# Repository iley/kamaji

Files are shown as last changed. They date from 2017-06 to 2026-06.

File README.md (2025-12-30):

# Kamaji quiz game system

See [kamaji.cc](http://kamaji.cc) for assembly instructions and additional information.



Directories:

* `firmware`: main source code;
* `demo`: code samples;
* `3d`: [OpenSCAD](http://www.openscad.org/) models for the enclosure;
* `pcb`: schematic and printed circuit board layout in [KiCAD](http://kicad-pcb.org/) format;
* `misc`: the rest.

## SDK

We use [PlatformIO](http://platformio.org) with
[Arduino](http://platformio.org/frameworks/arduino) framework. It should also
be possible to compile the code with the official Arduino IDE.

## Compile and flash firmware

For v1 and v3 custom fuses must be programmed before first flashing.

```
pio run -e v1 -t fuses
```

Select the correct board version (v1, v2, v3) and flash it with:

```
pio run -e v1 -t upload
```

## Hardware

**The recommended version for new builds is "Classic V1".**

* V1 uses an ATmega328p running at 8MHz without an external oscillator. [USBasp](http://www.fischl.de/usbasp/) can be used for programming.
* V2 uses ATmega32u4 and a 128x64 graphics screen.
* V3 runs on ATmega328p with a 16MHz oscillator and and utilizes a PCF8574 I/O extender chip.
* "Classic V1" is an updated revision of V1. Fully compatible from software point of view.
* "Headless" is a USB MIDI device without a screen or buttons. Built around "Pro Micro" boards (ATMega32U4).

## Code style

Let's stick to [Google C++ Style Guide](https://google.github.io/styleguide/cppguide.html).

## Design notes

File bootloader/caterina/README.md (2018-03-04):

# ATMega32u4 bootloader

This is a slightly modified version of the [Sparkfan Arduino bootloader][sf].

Program with [USBasp][usbasp]:

    avrdude -p atmega32u4 -P usb -c usbasp \
        -U flash:w:Caterina.hex \
        -U efuse:w:0xcb:m -U hfuse:w:0xd8:m -U lfuse:w:0xff:m

Hot bo rebuild:

1. Install avr-gcc and avr-libc.
2. Download [LUFA][lufa] version 111009 into `LUFA` directory.
3. Run `make`.

[usbasp]: http://www.fischl.de/usbasp/
[sf]: https://github.com/sparkfun/SF32u4_boards/tree/master/sparkfun/avr/bootloaders/caterina
[lufa]: http://www.fourwalledcubicle.com/LUFA.php

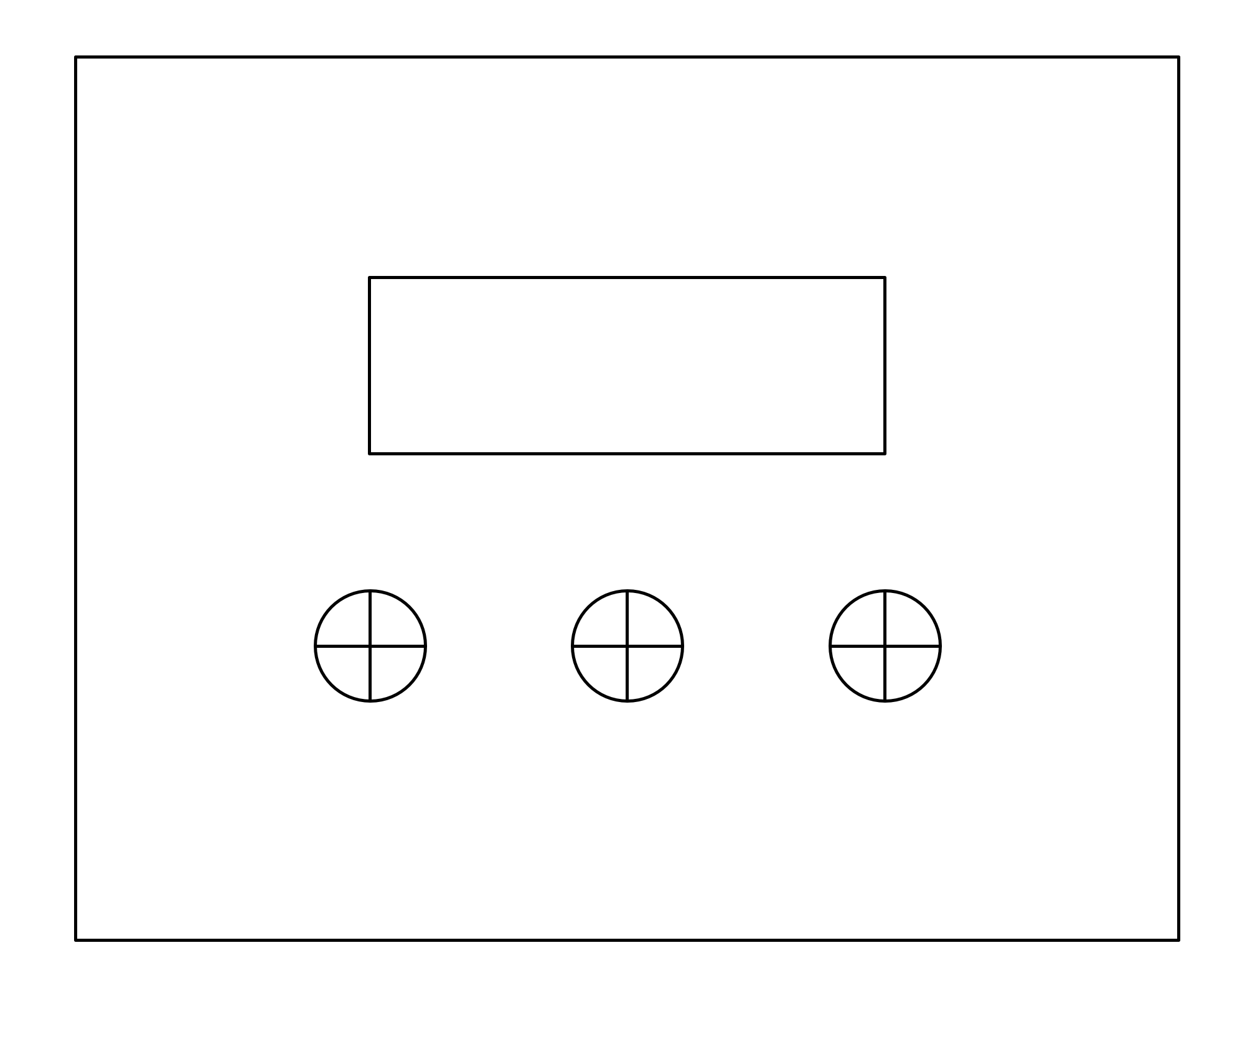
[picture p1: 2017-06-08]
misc/panel.png

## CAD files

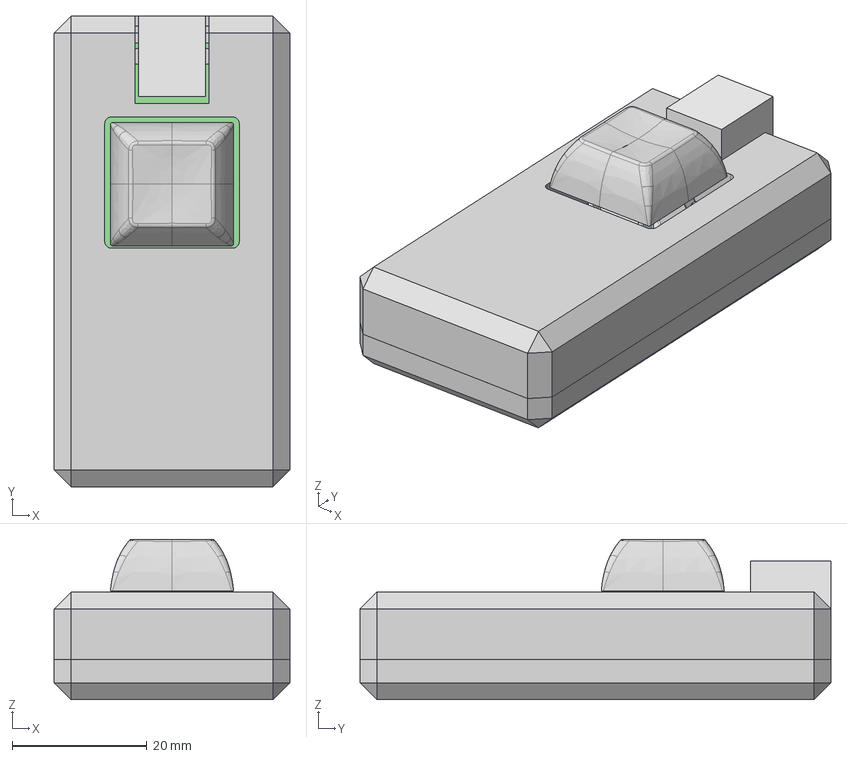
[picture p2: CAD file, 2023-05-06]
3d/button_v1/button_v1_shell.step
35.0 x 70.0 x 23.8 mm
kamaji_button_v1 PCB
SW_Cherry_MX_PCB v1
Keycap_adjusted v39 v1
case_top
case_bottom

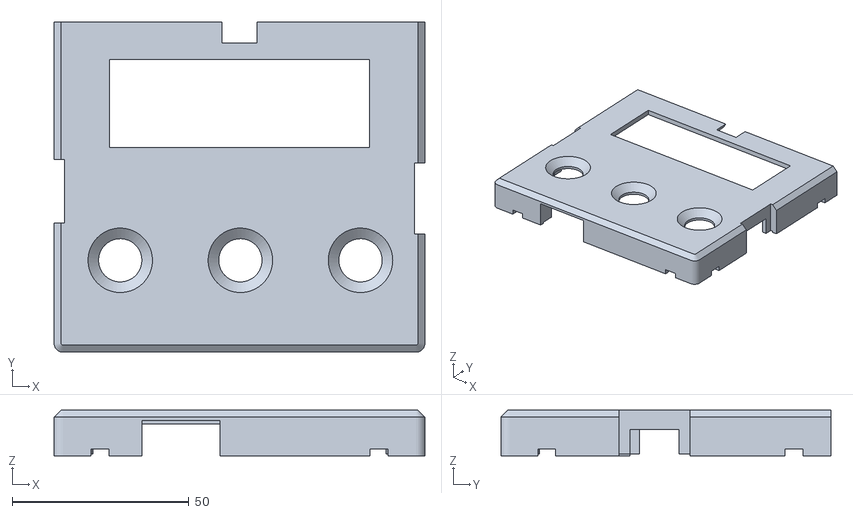
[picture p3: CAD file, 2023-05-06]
3d/classic_v1/kamaji_classic_v1_top.stl
105.0 x 93.5 x 13.0

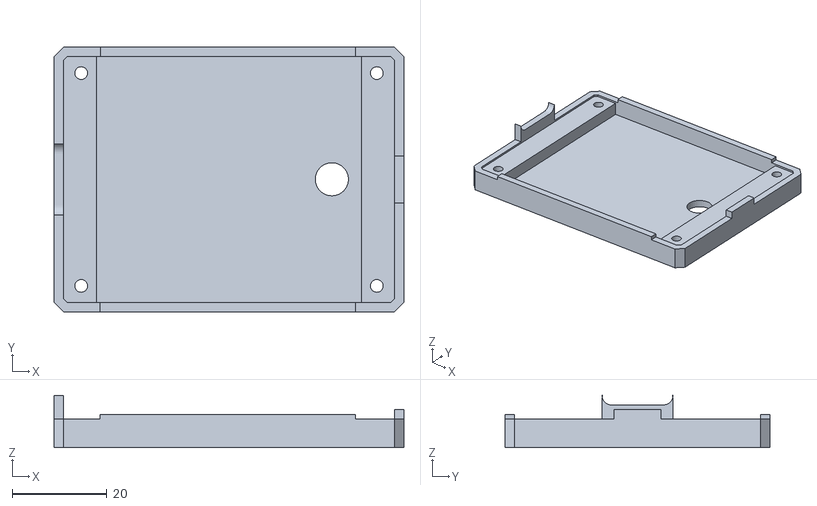
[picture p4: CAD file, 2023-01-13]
3d/headless_v1/bottom.stl
74.0 x 56.0 x 11.0

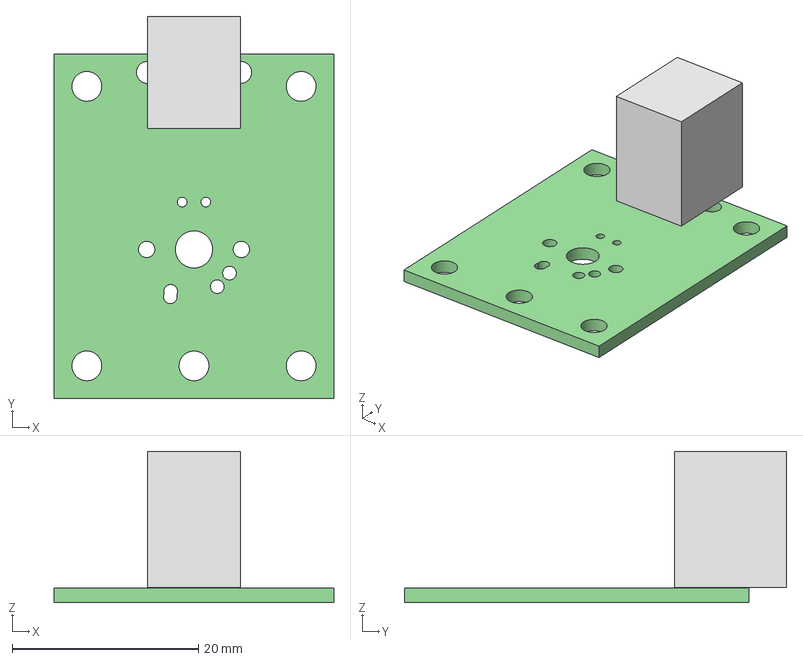
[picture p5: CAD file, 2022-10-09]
pcb/button_v1/kamaji_button_v1.STEP
30.0 x 41.0 x 16.2 mm
kamaji_button_v1 PCB

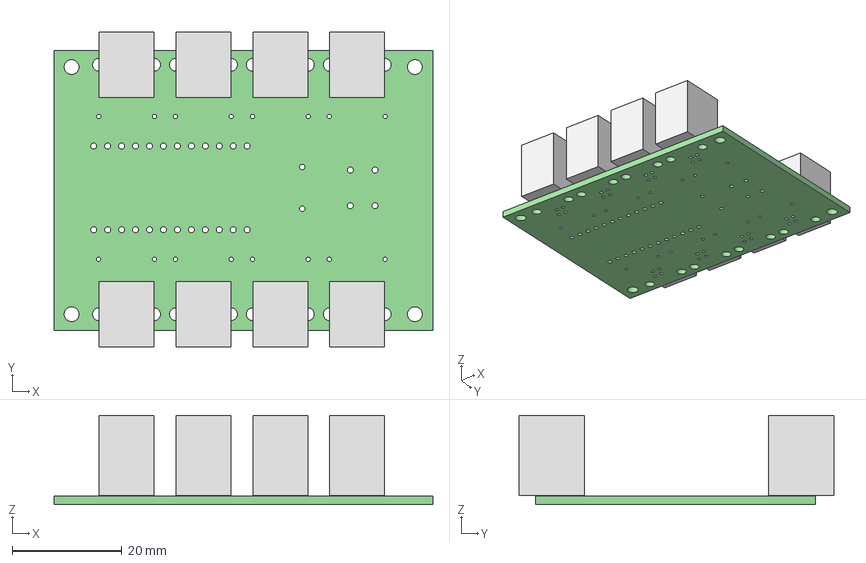
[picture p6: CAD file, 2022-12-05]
pcb/headless_v1/headless_v1.step
69.0 x 57.4 x 16.2 mm
headless_v1 PCB

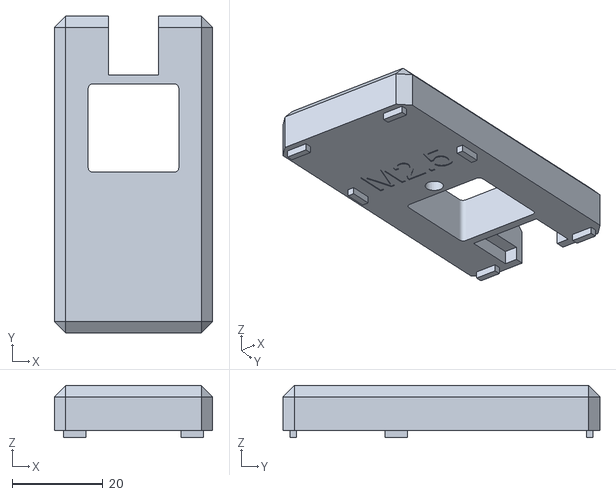
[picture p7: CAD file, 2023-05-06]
3d/button_v1/button_v1_top.stl
35.0 x 70.0 x 11.5

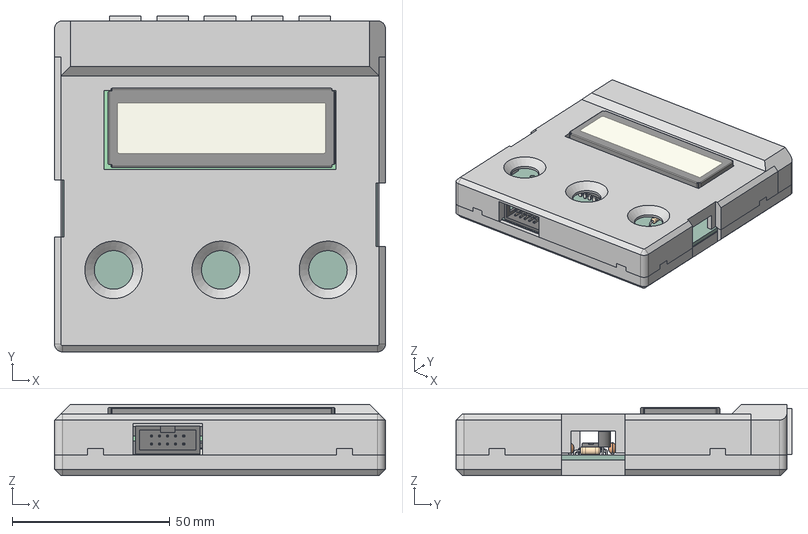
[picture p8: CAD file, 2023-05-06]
3d/classic_v1/kamaji_classic_v1_shell.step
105.0 x 106.5 x 22.6 mm
PCB
sockets_cover
top_shell
bottom_shell

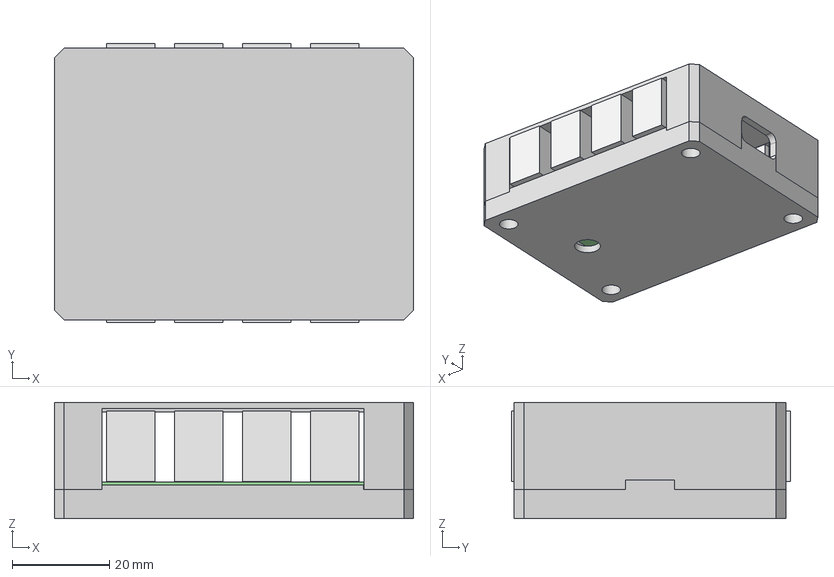
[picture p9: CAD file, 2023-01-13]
3d/headless_v1/kamaji_headless_v1.step
74.0 x 57.4 x 24.0 mm
headless_v1 PCB

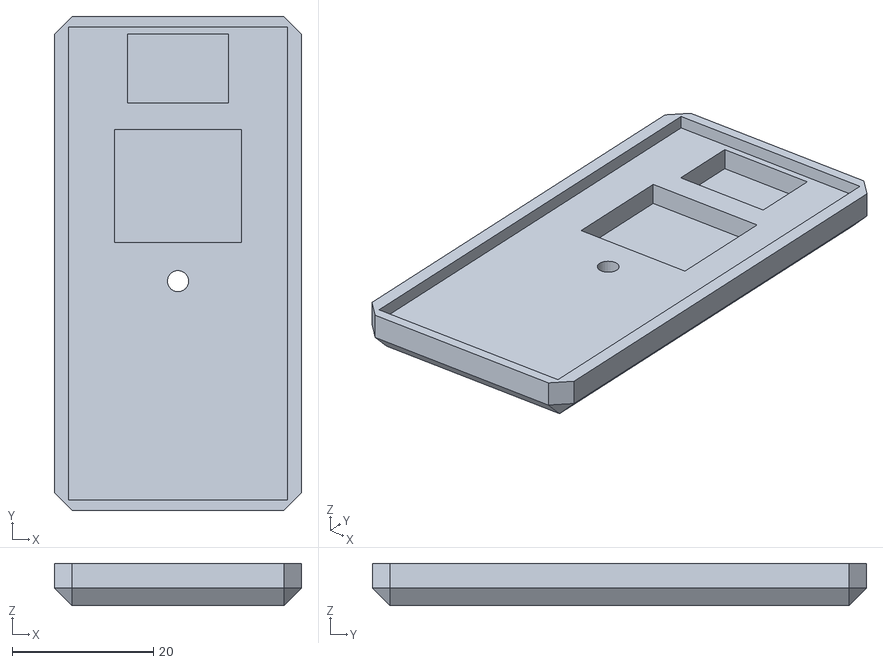
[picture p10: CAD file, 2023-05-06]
3d/button_v1/button_v1_bottom.stl
35.0 x 70.0 x 6.00

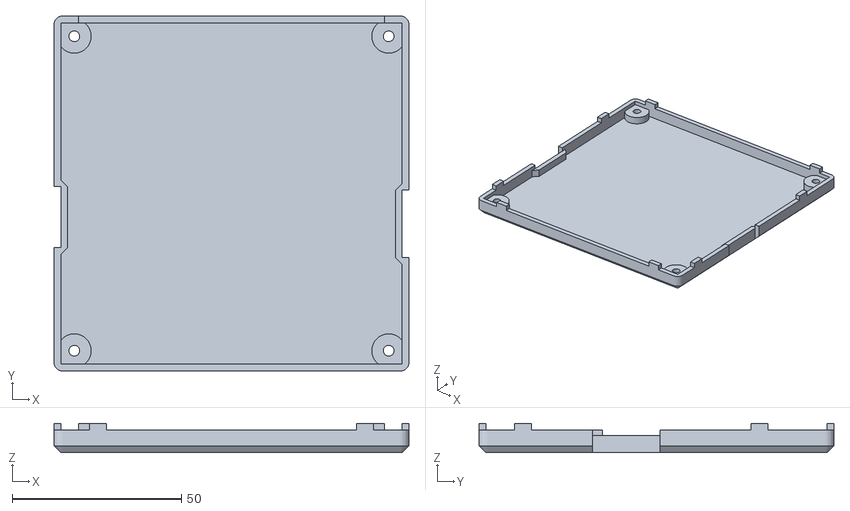
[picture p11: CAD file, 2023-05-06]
3d/classic_v1/kamaji_classic_v1_bottom.stl
105.0 x 105.0 x 8.60

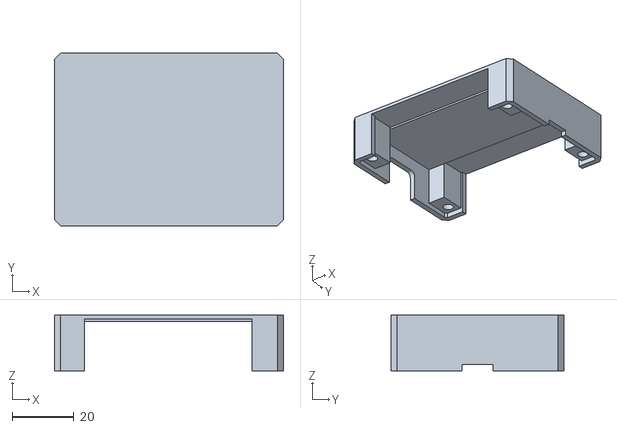
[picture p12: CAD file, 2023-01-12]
3d/headless_v1/top.stl
74.0 x 56.0 x 18.0

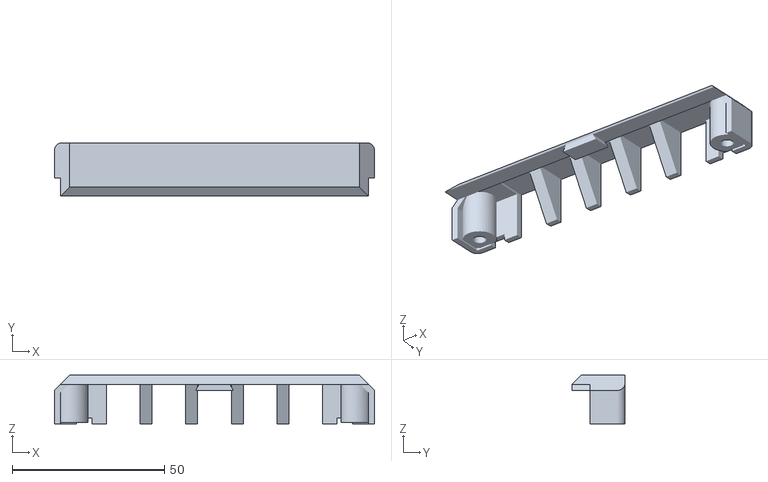
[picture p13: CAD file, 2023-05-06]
3d/classic_v1/kamaji_classic_v1_front_cover.stl
105.0 x 17.5 x 16.0

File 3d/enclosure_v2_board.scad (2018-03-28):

use <cubeX.scad>

tol = 0.25;
screen_tol = 0.8;
pcb_x = 100;
pcb_y = 100;
pcb_z = 4;
bolt_d = 3.6;
shift_bolt = 3;
shift_bolt_x = 4;
shift_bolt_y = 7;
board_w = 1;
board_h = 1;

m3_bolt_top_r = 2.9;
m3_bolt_top_h = 1.5;


// box thickness
th = 2;

// bolts
shift_x = th + 0.5;
shift_y = th + 0.5;

box_x = pcb_x + 2*th + 1;
box_y = pcb_y + 2*th + 1;

pcb_width = 1.8;

socket_h = 14.7;
socket_w = 10;
socket_n = 6;
socket_all_len = 85;
socket_int = socket_w + (socket_all_len - socket_n*socket_w)/(socket_n - 1);
start_socket_x = shift_x + (pcb_x - socket_all_len) / 2;
eps = 1e-1;

bottom_box_z = socket_h + th + pcb_width;

usb_type_b_w = 12;
usb_type_b_h = 11;
start_type_b_y = shift_y + pcb_y - 36.5;
start_type_b_z = bottom_box_z - pcb_width - usb_type_b_h - tol;

usb_type_a_w = 14.4;
usb_type_a_h = 6.3;
start_type_a_y = shift_y + 25;
start_type_a_z = bottom_box_z - pcb_width - usb_type_a_h - tol;

// programmator
micro_x = 10;
micro_y = 21.1;
micro_start_x = shift_x + 4.75;
micro_start_y = shift_y + pcb_y - 23.3 - micro_y;

contrast_start_x = shift_x + 38.4;
contrast_start_y = shift_y + 25.7;
//volume_start_x = shift_x + pcb_x - 39.2;
//volume_start_y = contrast_start_y;
pot_d = 7;
under_pcb = 13;
fn = 10;
gaika_h = 4;
gaika_w = 5.5;
stoiki_r = 4;
stoiki_h = socket_h;
wide_stoiki_r = stoiki_r + 2;

dynamic_x = shift_x + 19;
dynamic_y = shift_y + 30;
dynamic_r = 16;

volume_center_y = shift_y + 50;
volume_w = 15;
volume_start_y = volume_center_y - volume_w/2;
volume_h = 4;
round_radius=2;

translate([0,0,-50]) {

// put exclamation mark here to render bottom
difference() {
  union() {
    difference() {
      union() {
        cubeBottomX([box_x, box_y, bottom_box_z-board_h], radius=round_radius);
        translate([th - board_w, th - board_w, 0]) {
          cubeBottomX([box_x - 2*(th - board_w), box_y - 2*(th - board_w), bottom_box_z], radius=round_radius);
        }
      }
      translate([th, th, th]) {
        cubeBottomX([box_x-2*th+eps, box_y-2*th+eps, bottom_box_z-th+eps], radius=round_radius);
      }
    }
    // under_pcb, stoiki
    for (dy = [shift_y+shift_bolt_y, shift_y+pcb_y-shift_bolt_y]) {
      for (dx = [shift_x+shift_bolt_x, shift_x+pcb_x-shift_bolt_x]) {
        translate([dx,dy,th-eps]) {
          cylinder($fn=6, r=stoiki_r, h=stoiki_h + eps);
          //cylinder($fn=6, r=wide_stoiki_r, h=gaika_h);
        }
      }
    }
   translate([start_socket_x, th - eps, th - eps]) {
     cube([socket_all_len, th/2 + eps, stoiki_h + eps]);
   }
    //translate([box_x/2, box_y/2, th-eps]) {
      //cylinder($fn=6, r=stoiki_r, h=pcb_up);
    //}
  }

  // dynamic
  translate([dynamic_x, dynamic_y, -eps]) {
      cylinder($fn=20, r=dynamic_r, h = th+2*eps);
  }

  // sockets
  for (i = [0:1:socket_n-1]) {
      translate([start_socket_x+i*socket_int - tol, -eps, bottom_box_z - socket_h - pcb_width]) {
        cube(size=[socket_w + 2*tol, socket_h, socket_h + socket_h]);
      }
  }
  // bolts
  for (dx = [shift_x+shift_bolt_x, shift_x+pcb_x-shift_bolt_x]) {
    for (dy = [shift_y+shift_bolt_y, shift_y+pcb_y-shift_bolt_y]) {
      translate([dx,dy,-eps]) {
        cylinder($fn=fn, r=bolt_d/2, h=th+stoiki_h+2*eps);
        // bolt
        cylinder($fn=12, r=m3_bolt_top_r + 0.05, h=m3_bolt_top_h);
      }
    }
  }

//    // usb_in1 type b
    translate([box_x-th-eps, start_type_b_y-tol, start_type_b_z]) {
        cube(size=[th+2*eps, usb_type_b_w + 2*tol, bottom_box_z]);
    }

    // usb_out1 type a
    translate([box_x - eps - th, start_type_a_y - tol, start_type_a_z]) {
        cube(size=[th+2*eps, usb_type_a_w + 2*tol, bottom_box_z]);
    }

    // volume
    translate([-eps, volume_start_y, bottom_box_z - pcb_width - volume_h]) {
        cube(size=[th+2*eps, volume_w, volume_h + pcb_width + eps]);
    }

}
}

top_box_z = 10;
//stoiki_h = top_box_z - th;
wide_stoiki_h = 5;
pcb_room = 1;
screen_start_x = shift_x + 11.5;
screen_start_y = shift_y + 25;
screen_length_x = 77;
screen_length_y = 50.5;
screen_hold_x = 40;
screen_hold_y = 4;
screen_hold_start_z = 12.5;
screen_hold_y_shift = 2;
screen_hold_up_x = 15;
screen_hold_up_x_shift = 5;

master_button_y = shift_y + pcb_y - 7.5;
master_button_x = shift_x + 19;
master_button_int = 31.5;
master_button_r = 6.5;
top_bolt_h = 1.5;
top_bolt_r = 3.5;

// put exclamation mark here to render top
!rotate(a=[180,0,0]) {
difference() {
  union() {
    // board
    translate([0, 0, -board_h]) {
        difference() {
            cubeSideX(size=[box_x, box_y, board_h + eps], radius=round_radius, center=false);
            translate([board_w, board_w, -eps]) {
                cubeSideX(size=[box_x - 2*board_w, box_y - 2*board_w, board_h + 3*eps], radius=round_radius, center=false);
            }
        }
    }
    difference() {
      cubeTopX(size=[box_x,box_y,top_box_z], radius=round_radius, center=false);
      translate([th, th, -eps]) {
        cubeTopX(size=[box_x-2*th+eps, box_y-2*th+eps, top_box_z-th+eps], radius=round_radius, center=false);
      }
    }
    // stoiki
    for (dx = [shift_x+shift_bolt_x, shift_x+pcb_x-shift_bolt_x]) {
      for (dy = [shift_y+shift_bolt_y, shift_y+pcb_y-shift_bolt_y]) {
        translate([dx,dy,-eps]) {
          cylinder($fn=6, r=stoiki_r-0.5, h=top_box_z-th+eps);
        }
        translate([dx,dy,top_box_z-th-wide_stoiki_h+eps]) {
          cylinder($fn=6, r=wide_stoiki_r, h=wide_stoiki_h-2*eps);
        }
      }
    }
  }
  // bolts
  for (dx = [shift_x+shift_bolt_x, shift_x+pcb_x-shift_bolt_x]) {
    for (dy = [shift_y+shift_bolt_y, shift_y+pcb_y-shift_bolt_y]) {
      translate([dx,dy,-2*eps]) {
        cylinder($fn=fn, r=bolt_d/2, h=top_box_z+2*eps);
      }
      translate([dx, dy, top_box_z - wide_stoiki_h]) {
        cylinder($fn=6, r=gaika_w / 2 / cos(30) + 0.05, h=wide_stoiki_h+eps);
        //cylinder($fn=6, r=top_bolt_r, h=top_bolt_h + eps);
      }
    }
  }

  // screen
  translate([screen_start_x - screen_tol, screen_start_y - screen_tol, top_box_z - th - eps]) {
      cube([screen_length_x + 2*screen_tol, screen_length_y + 2*screen_tol, th + 2*eps]);
  }
  // master buttons
  for (i = [0:1:2]) {
    translate([master_button_x + master_button_int*i, master_button_y, top_box_z - th - eps]) {
      cylinder($fn=20, r=master_button_r + tol, h=th+2*eps);
    }
  }
}
}


//// bolts
//for (dx = [shift_x+shift_bolt, shift_x+pcb_x-shift_bolt]) {
//  for (dy = [shift_y+shift_bolt, shift_y+pcb_y-shift_bolt]) {
//    difference() {
//      translate([dx,dy,pcb_up/2+th]) {
//        cube(size=[a,a,pcb_up], center=true);
//      }
//      translate([dx,dy,-eps]) {
//        cylinder($fn=20, r=bolt_d/2, h=th+pcb_up+2*eps);
//      }
//    }
//  }
//}


//leg_r = t;
//shift = t/2+leg_r;
//for (dx = [shift, a-shift])
//    for (dy = [shift, b-shift]) {
//        translate([dx, dy, 0]) {
//            cylinder(h=c, r=leg_r, $fn=40);
//        }
//    }

module roundedRect(size, radius)
{
    x = size[0];
    y = size[1];
    z = size[2];
    translate([x/2,y/2,0]) {
    linear_extrude(height=z)
        hull()
        {
            // place 4 circles in the corners, with the given radius
            translate([(-x/2)+(radius/2), (-y/2)+(radius/2), 0])
                circle(r=radius);

            translate([(x/2)-(radius/2), (-y/2)+(radius/2), 0])
                circle(r=radius);

            translate([(-x/2)+(radius/2), (y/2)-(radius/2), 0])
                circle(r=radius);

            translate([(x/2)-(radius/2), (y/2)-(radius/2), 0])
                circle(r=radius);
        }
    }
}

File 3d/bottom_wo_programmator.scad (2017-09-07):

tol = 0.5;
pcb_x = 130;
pcb_y = 110;
pcb_z = 4;
bolt_d = 3.6;
shift_bolt = 5;

// box thickness
th = 2;

shift_x = 4;
shift_y = th + 1;

box_x = pcb_x + shift_x + 4;
box_y = pcb_y + shift_y + th;

pcb_width = 2;
pcb_up = 2;

box_z = th + pcb_up + pcb_width - 1;

socket_h = 15;
socket_w = 10;
socket_n = 5;
socket_int = 20;
start_socket_x = 20 + shift_x;
start_socket_z = th + pcb_z + tol;
eps = 1e-1;

usb_type_b_w = 12;
usb_type_b_h = 11;
start_type_b_y = shift_y + 81.5;
//start_type_b_z = th + pcb_z + tol;

usb_type_a_w = 13.4;
usb_type_a_h = 7.3;
start_type_a_y = shift_y + 47;
//start_type_a_z = th + pcb_z + tol;

// programmator
micro_x = 10;
micro_y = 21.1;
micro_start_x = shift_x + 4.75;
micro_start_y = shift_y + pcb_y - 23.3 - micro_y;

contrast_start_x = shift_x + 38.4;
contrast_start_y = shift_y + 25.7;
volume_start_x = shift_x + pcb_x - 39.2;
volume_start_y = contrast_start_y;
pot_d = 7;
fn = 10;
gaika_h = 2;
gaika_w = 5.6;
stoiki_r = 4;
wide_stoiki_r = stoiki_r + 2;



translate([0,0,-50]) {

!difference() {
  union() {
    difference() {
      cube([box_x,box_y,box_z], false);
      translate([th, th, th]) {
        cube([box_x-2*th+eps, box_y-2*th+eps, box_z-th+eps], false);
      }
    }
    // stoiki
    for (dy = [shift_y+shift_bolt, shift_y+pcb_y-shift_bolt]) {
      for (dx = [shift_x+shift_bolt, shift_x+pcb_x-shift_bolt]) {
        translate([dx,dy,th-eps]) {
          cylinder($fn=6, r=stoiki_r, h=pcb_up);
          cylinder($fn=6, r=wide_stoiki_r, h=gaika_h);
        }
      }
    }
    translate([box_x/2, box_y/2, th-eps]) {
      cylinder($fn=6, r=stoiki_r, h=pcb_up);
    }
  }

  // bolts
  for (dx = [shift_x+shift_bolt, shift_x+pcb_x-shift_bolt]) {
    for (dy = [shift_y+shift_bolt, shift_y+pcb_y-shift_bolt]) {
      translate([dx,dy,-eps]) {
        cylinder($fn=fn, r=bolt_d/2, h=th+pcb_up+2*eps);
        // gaika
        cylinder($fn=6, r=gaika_w / 2 / cos(30) + 0.05, h=gaika_h);
      }
    }
  }

//    for (i = [0:1:socket_n-1]) {
//        translate([start_socket_x+i*socket_int-tol, box_y-th-eps, start_socket_z]) {
//            cube(size=[socket_w+2*tol, th+2*eps, box_z]);
//        }
//    }

//    // usb_in1 type b
//    translate([box_x-th-eps, start_type_b_y-tol, start_type_b_z]) {
//        cube(size=[th+2*eps, usb_type_b_w+2*tol, box_z]);
//    }

//    // usb_out1 type a
//    translate([-eps, start_type_a_y - tol, start_type_a_z]) {
//        cube(size=[th+2*eps, usb_type_a_w + 2*tol, box_z]);
//    }

    // programmator
    //translate([micro_start_x-tol,micro_start_y-tol, -eps]) {
      //cube(size=[micro_x+2*tol, micro_y+2*tol, th+2*eps]);
    //}

    // contrast
    //translate([contrast_start_x, contrast_start_y, -eps]) {
      //cylinder($fn=fn, r=pot_d/2, h=th+2*eps);
    //}

    // volume
//    translate([volume_start_x, volume_start_y, -eps]) {
//      cylinder($fn=20, r=pot_d/2, h=th+2*eps);
//    }
}
}

top_box_z = 15 + th;
stoiki_h = top_box_z - th;
wide_stoiki_h = 2;
pcb_room = 0.5;
screen_start_x = shift_x + 28;
screen_start_y = shift_y + 40;
screen_length_x = 72;
screen_length_y = 24;
screen_hold_x = 40;
screen_hold_y = 4;
screen_hold_start_z = 12;
screen_hold_y_shift = 2;
screen_hold_up_x = 25;
screen_hold_up_x_shift = 5;

master_button_y = shift_y + 10;
master_button_x = shift_x + 43;
master_button_int = 21.8;
master_button_r = 3;
top_bolt_h = 1.5;
top_bolt_r = 3.5;
speaker_shift = 18;
speaker_r = 15;
speaker_h = 15;
speaker_hole_d = 10;
speaker_hole_int = 3;
speaker_hole_w = 1.5;
speaker_shift = 18;

difference() {
  union() {
    difference() {
      cube([box_x,box_y,top_box_z], false);
      translate([th, th, -eps]) {
        cube([box_x-2*th+eps, box_y-2*th+eps, top_box_z-th+eps], false);
      }
    }
    // stoiki
    for (dx = [shift_x+shift_bolt, shift_x+pcb_x-shift_bolt]) {
      for (dy = [shift_y+shift_bolt, shift_y+pcb_y-shift_bolt]) {
        translate([dx,dy,pcb_room]) {
	  cylinder($fn=6, r=stoiki_r, h=top_box_z-th+eps);
        }
        translate([dx,dy,top_box_z-th-wide_stoiki_h+eps]) {
	  cylinder($fn=6, r=wide_stoiki_r, h=wide_stoiki_h+th-2*eps);
        }
      }
    }
    // screen_hold
    translate([screen_start_x + (screen_length_x - screen_hold_x)/2, screen_start_y - screen_hold_y_shift - screen_hold_y, screen_hold_start_z]) {
	cube([screen_hold_x, screen_hold_y, top_box_z - screen_hold_start_z - th + eps]);
    }
    translate([screen_start_x + screen_length_x - screen_hold_up_x - screen_hold_up_x_shift, screen_start_y + screen_length_y + screen_hold_y_shift, screen_hold_start_z]) {
	cube([screen_hold_up_x, screen_hold_y, top_box_z - screen_hold_start_z - th + eps]);
    }
  }
  // - speaker na stoikah
  translate([shift_x + pcb_x - 18, shift_y + 18, 0]) {
    cylinder(r=speaker_r, h = 15, $fn=20);
  }
  // speaker_hole
  for (dy = [shift_y + speaker_shift - speaker_hole_int - speaker_hole_w*3/2, 
             shift_y + speaker_shift - speaker_hole_w/2, 
             shift_y + speaker_shift + speaker_hole_int + speaker_hole_w/2]) { 
    translate([shift_x + pcb_x - speaker_shift - speaker_hole_d, dy, top_box_z-th-eps]) {
      cube(size=[speaker_hole_d, speaker_hole_w, th + 2*eps]);
    }
  }

  // bolts
  for (dx = [shift_x+shift_bolt, shift_x+pcb_x-shift_bolt]) {
    for (dy = [shift_y+shift_bolt, shift_y+pcb_y-shift_bolt]) {
      translate([dx,dy,-eps]) {
        cylinder($fn=fn, r=bolt_d/2, h=top_box_z+2*eps);
      }
      translate([dx, dy, top_box_z - top_bolt_h]) {
        cylinder($fn=6, r=top_bolt_r, h=top_bolt_h + eps);
      }
    }
  }

  // screen
  translate([screen_start_x, screen_start_y, top_box_z - th - eps]) {
      cube([screen_length_x, screen_length_y + tol, th + 2*eps]);
  }
  // sockets
  for (i = [0:1:socket_n-1]) {
      translate([start_socket_x+i*socket_int-tol, box_y-th-eps, -eps]) {
	  cube(size=[socket_w+2*tol, th+2*eps, socket_h]);
      }
  }
  // type_b
  translate([box_x - th - eps, start_type_b_y - tol, -tol]) {
      cube([th + 2*eps, usb_type_b_w + 2*tol, usb_type_b_h + 2*tol]);
  }
  // type_a
  translate([-eps, start_type_a_y, -eps]) {
      cube([th + 2*eps, usb_type_a_w+eps, usb_type_a_h+2*eps]);
  }
  // master buttons
  for (i = [0:1:2]) {
    translate([master_button_x + master_button_int*i, master_button_y, top_box_z - th - eps]) {
      cylinder($fn=fn, r=master_button_r+tol, h=th+2*eps);
    }
  }
}


//// bolts
//for (dx = [shift_x+shift_bolt, shift_x+pcb_x-shift_bolt]) {
//  for (dy = [shift_y+shift_bolt, shift_y+pcb_y-shift_bolt]) {
//    difference() {
//      translate([dx,dy,pcb_up/2+th]) {
//        cube(size=[a,a,pcb_up], center=true);
//      }
//      translate([dx,dy,-eps]) {
//        cylinder($fn=20, r=bolt_d/2, h=th+pcb_up+2*eps);
//      }
//    }
//  }
//}


//leg_r = t;
//shift = t/2+leg_r;
//for (dx = [shift, a-shift])
//    for (dy = [shift, b-shift]) {
//        translate([dx, dy, 0]) {
//            cylinder(h=c, r=leg_r, $fn=40);
//        }
//    }

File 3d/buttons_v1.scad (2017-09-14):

$fn = 50;
button_h = 13;
overlap = 5;
//total_height = 22;
total_height = 19;
th = 2; // enclosure thickness
eps = 1e-1;

cap_r = 10.2 / 2;
cap_h = total_height - button_h + overlap;
cap_r_bottom = 3;

border_offset = 4 + th;
border_h = 3;
border_r = cap_r + 2;

socket_r = 3.2 / 2;

difference() {
  union() {
    cylinder(r=cap_r_bottom, h=cap_h);
    translate([0, 0, cap_h - border_h - border_offset]) {
      cylinder(r=border_r, h=border_h);
      cylinder(r=cap_r, h=border_h + border_offset);
    }
  }
  translate([0, 0, -eps]) {
    cylinder(r=socket_r, h=overlap+eps);
  }
}

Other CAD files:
3d/cubeX.scad
3d/classic_v1/kamaji_classic_v1_shell.f3z
3d/enclosure_v1.scad
3d/enclosure_v1_board.scad
3d/headless_v1/kamaji_headless_v1.f3z
3d/lcd_support_v1.scad
3d/legacy/cubeX.scad
3d/legacy/enclosure_v1.scad
3d/legacy/enclosure_v1_board.scad
3d/legacy/lcd_support_v1.scad

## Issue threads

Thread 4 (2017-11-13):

Visual signal for Brain Ring

ramosian-glider, 2017-11-13:
Replace it with something more handy, e.g. build a LED into the hull.

iley, 2017-11-13:
We may keep USB too in addition to an LED.

iley, 2017-11-13:
Possible options:
1) keep USB
2) add an LED on the hull
3) use a dedicated player button
4) signal using LEDs on the player buttons
5) replace the LED on player buttons with an RGB one

Closed 2018-03-04.

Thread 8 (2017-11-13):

Protection against powerbank auto-shutdown

iley, 2017-11-13:

iley, 2017-11-22:
Turning on a 100mA dummy load for 1 second every 10 seconds seems to work for the powerbanks we tested.

Closed 2017-12-22.

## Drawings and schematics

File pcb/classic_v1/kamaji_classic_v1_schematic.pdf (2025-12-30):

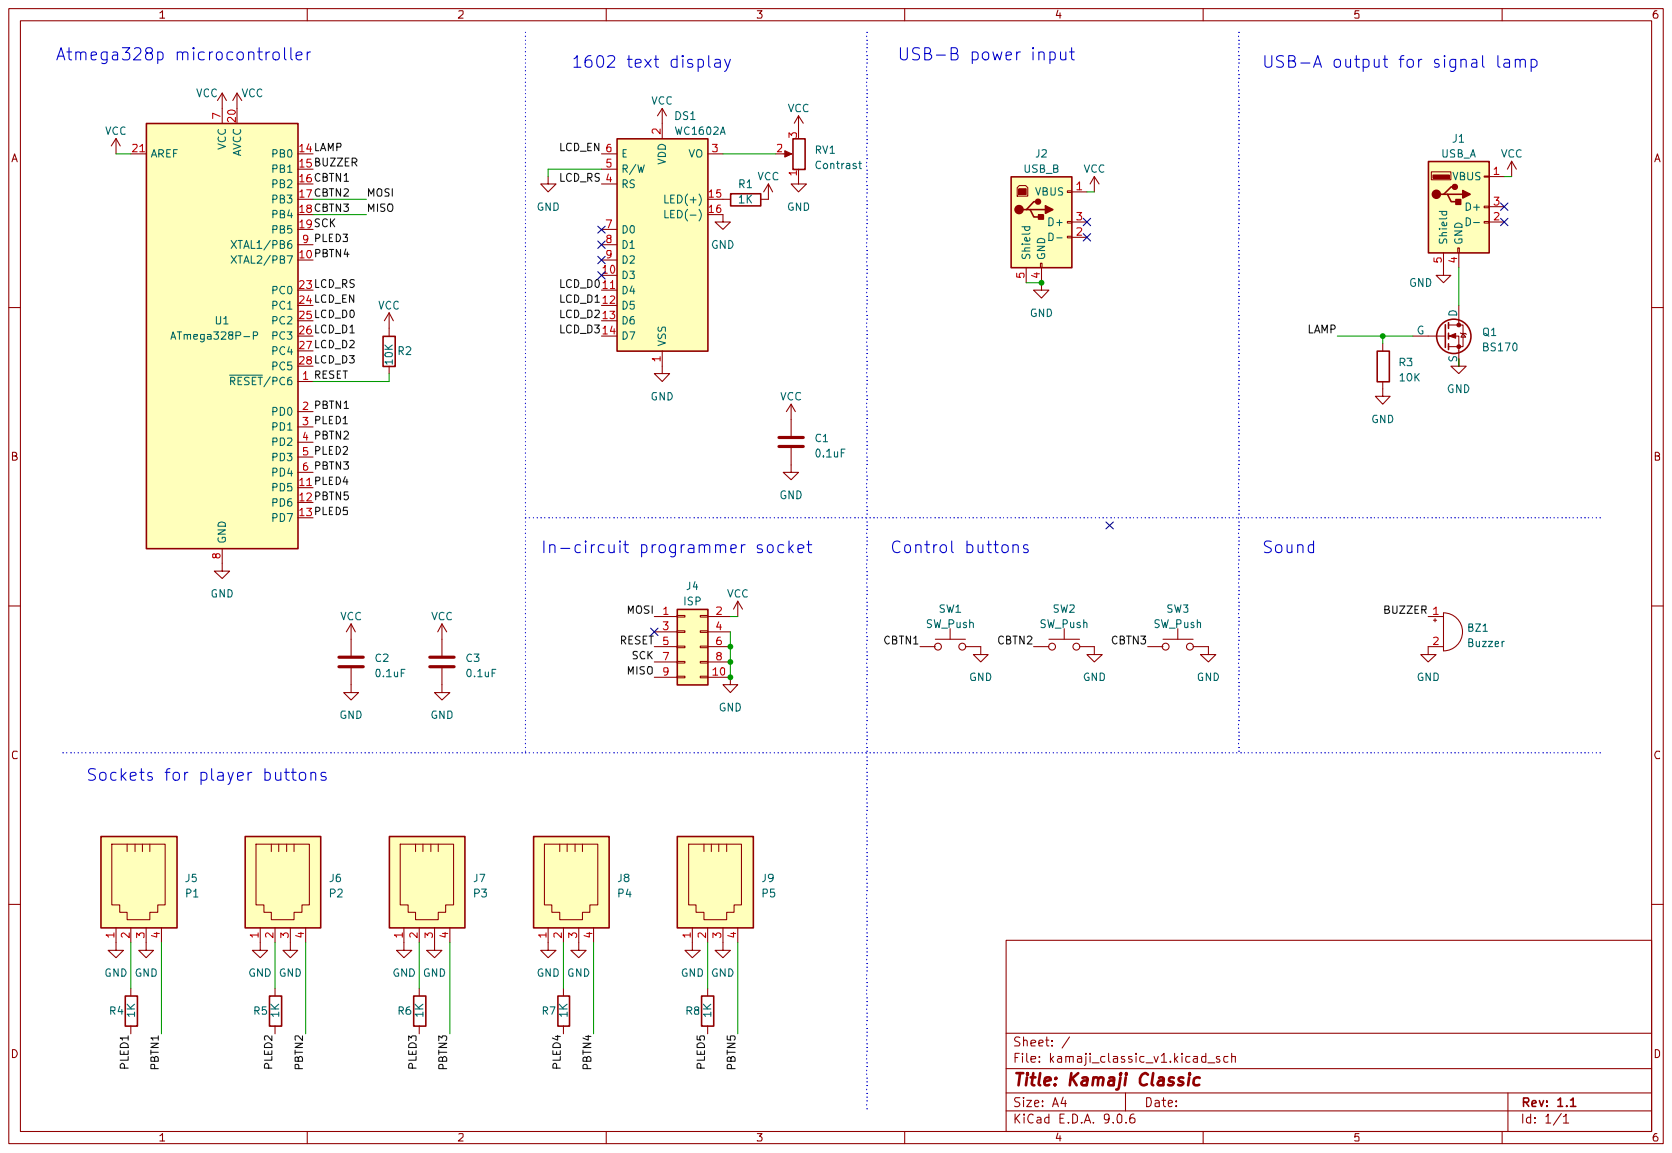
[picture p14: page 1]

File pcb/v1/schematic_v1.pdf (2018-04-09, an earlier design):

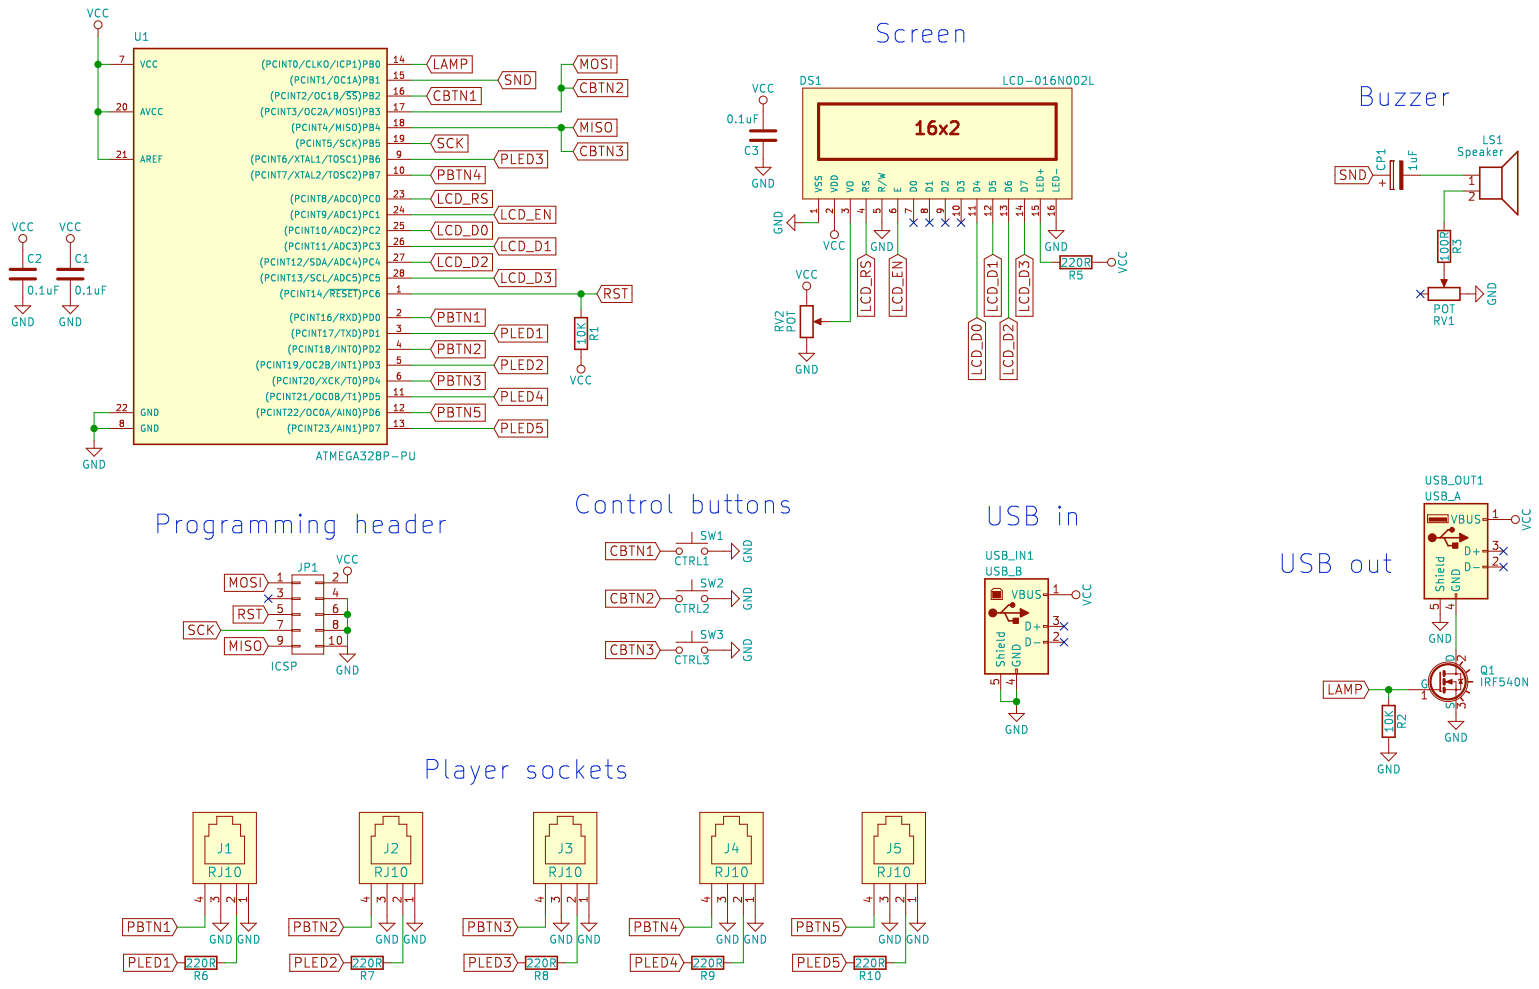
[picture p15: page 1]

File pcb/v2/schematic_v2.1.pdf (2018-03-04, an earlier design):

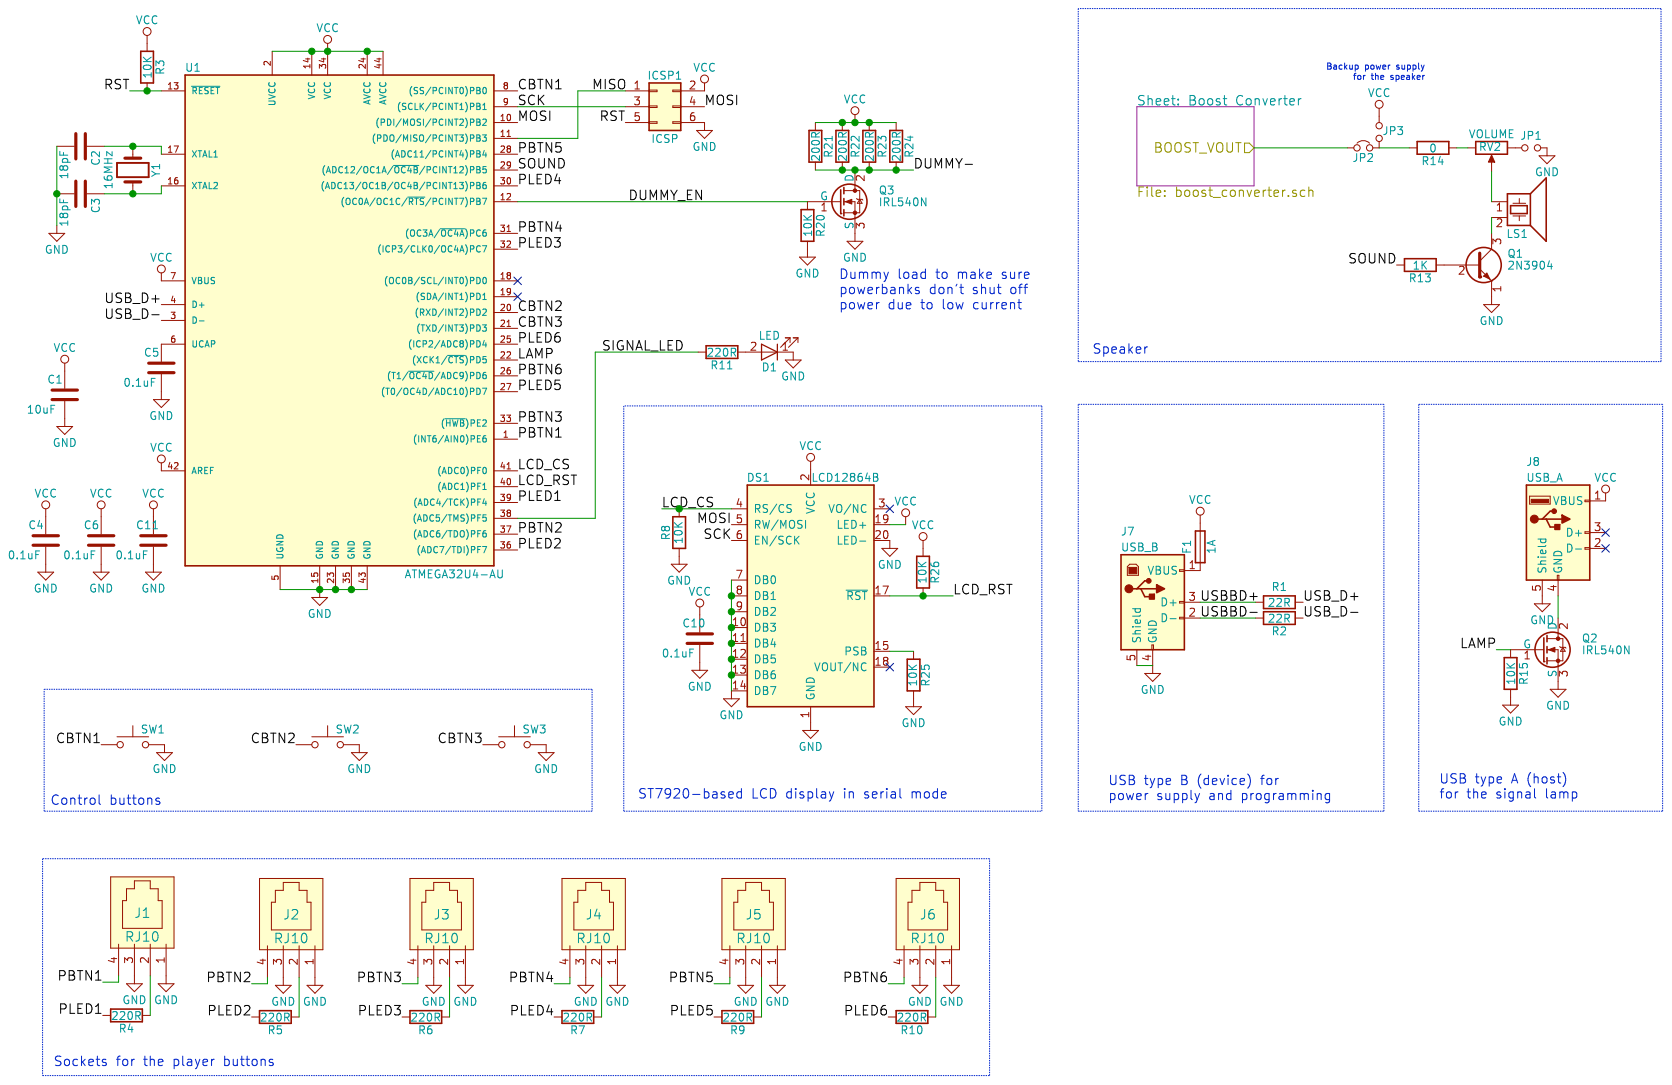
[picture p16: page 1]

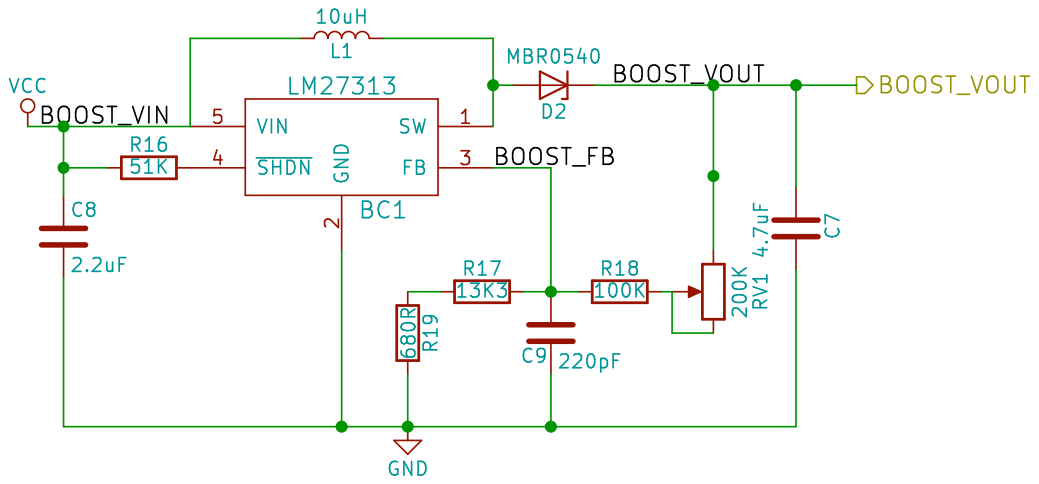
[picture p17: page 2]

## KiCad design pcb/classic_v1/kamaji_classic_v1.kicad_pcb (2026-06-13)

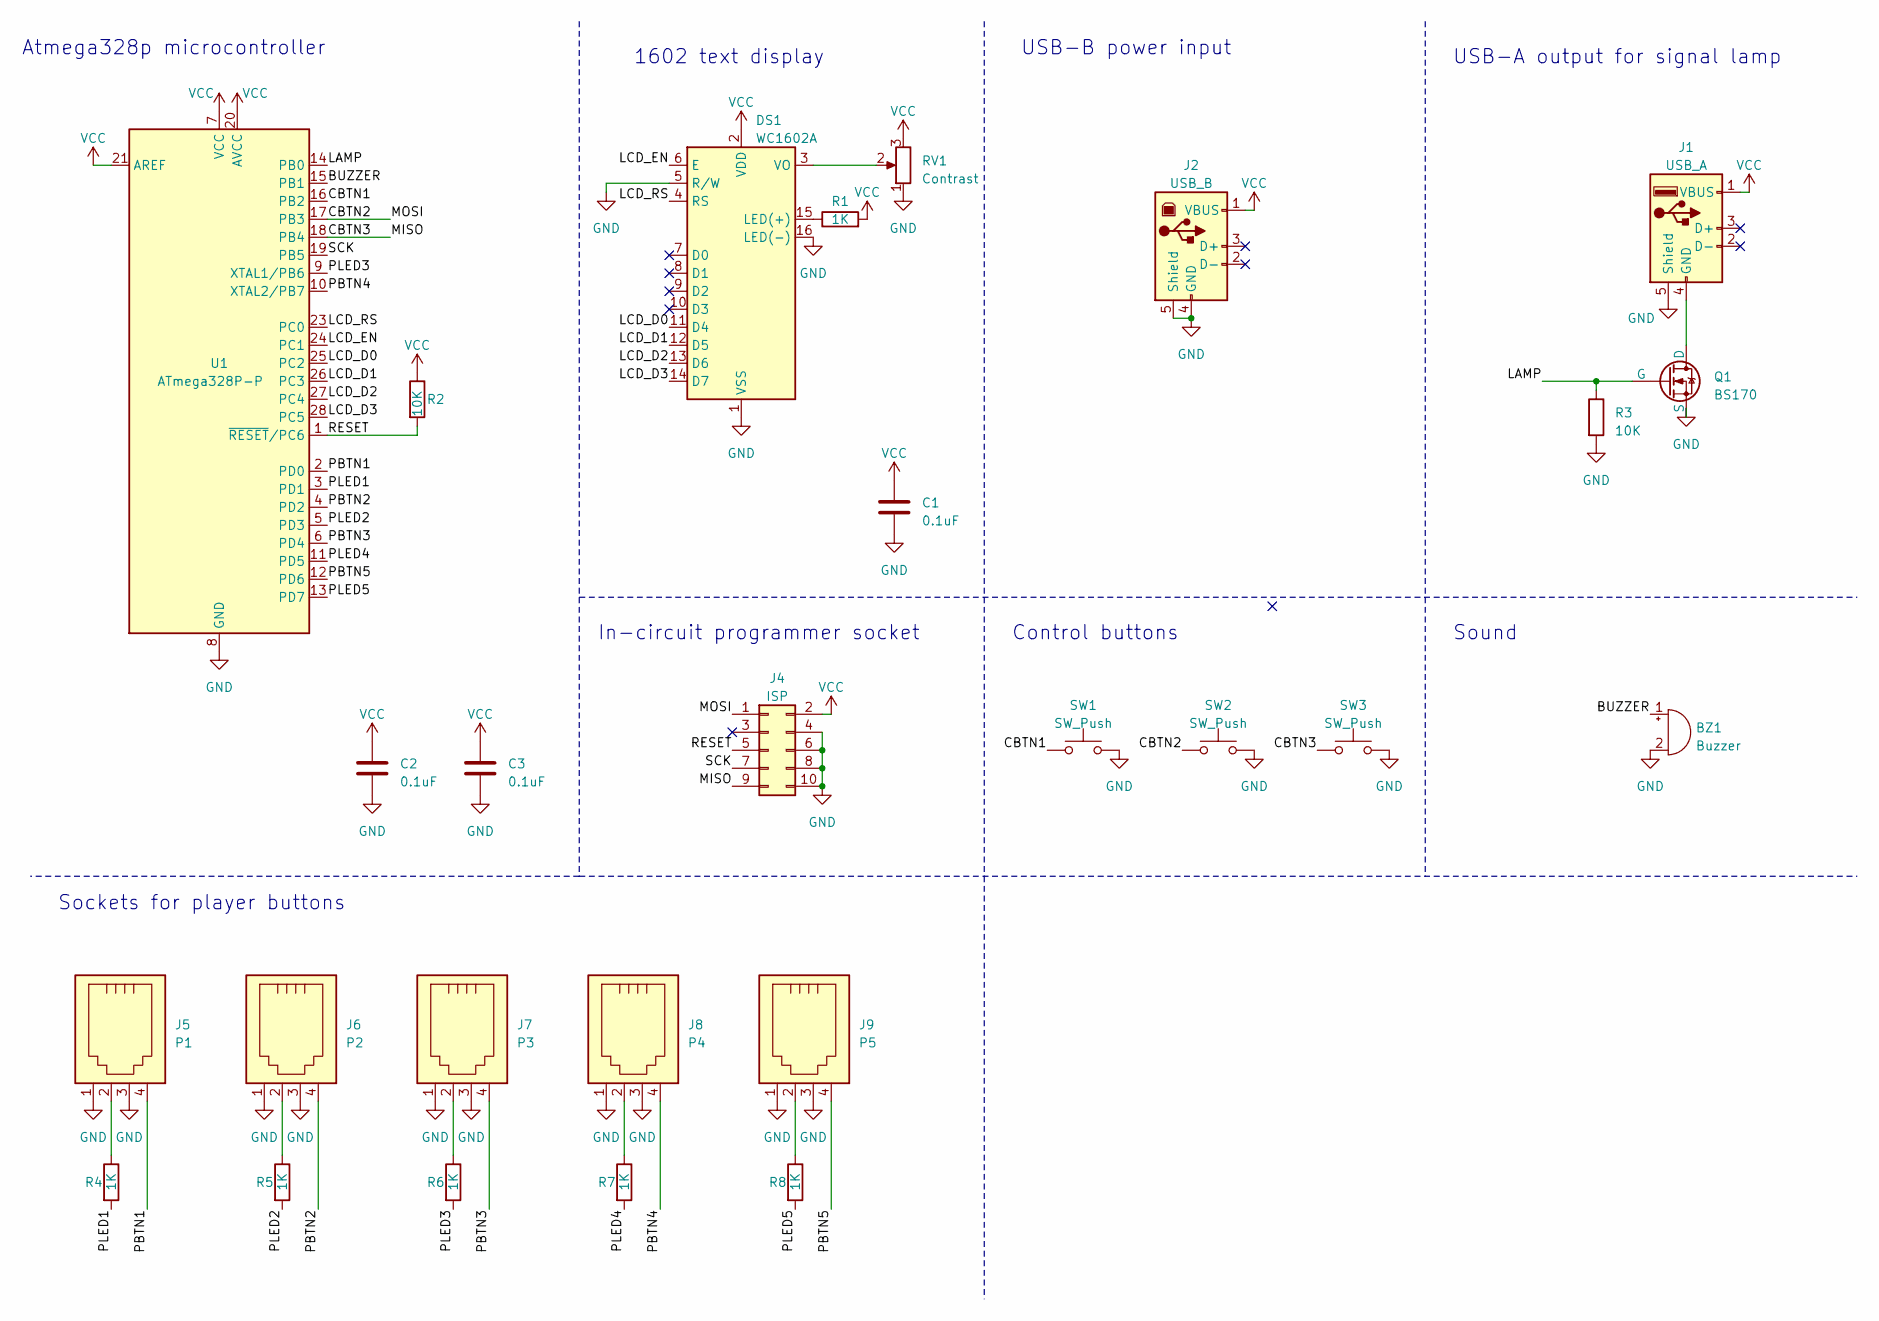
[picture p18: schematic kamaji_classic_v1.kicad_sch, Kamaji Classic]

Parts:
BZ1: Buzzer; Buzzer_12x9.5RM7.6
C1, C2, C3: 0.1uF; C_Disc_D3.8mm_W2.6mm_P2.50mm
DS1: WC1602A
J1: USB_A; USB_A_Connfly_DS1095
J2: USB_B; USB_B_Lumberg_2411_02_Horizontal
J4: ISP; IDC-Header_2x05_P2.54mm_Horizontal
J5: P1; RJ10
J6: P2; RJ10
J7: P3; RJ10
J8: P4; RJ10
J9: P5; RJ10
Q1: BS170; TO-92_HandSolder
R1, R4, R5, R6, R7, R8: 1K; R_Axial_DIN0207_L6.3mm_D2.5mm_P10.16mm_Horizontal
R2, R3: 10K; R_Axial_DIN0207_L6.3mm_D2.5mm_P10.16mm_Horizontal
RV1: Contrast; Potentiometer_Vishay_T73YP_Vertical
SW1, SW2, SW3: SW_Push; SW_PUSH-12mm
U1: ATmega328P-P; DIP-28_W7.62mm

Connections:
/BUZZER: BZ1.1 (-), U1.15 (PB1)
/CBTN1: SW1.1, U1.16 (PB2)
/CBTN2: J4.1, SW2.1, U1.17 (PB3)
/CBTN3: J4.9, SW3.1, U1.18 (PB4)
/LAMP: Q1.2 (G), R3.1, U1.14 (PB0)
/LCD_D0: DS1.11 (D4), U1.25 (PC2)
/LCD_D1: DS1.12 (D5), U1.26 (PC3)
/LCD_D2: DS1.13 (D6), U1.27 (PC4)
/LCD_D3: DS1.14 (D7), U1.28 (PC5)
/LCD_EN: DS1.6 (E), U1.24 (PC1)
/LCD_RS: DS1.4 (RS), U1.23 (PC0)
/PBTN1: J5.4, U1.2 (PD0)
/PBTN2: J6.4, U1.4 (PD2)
/PBTN3: J7.4, U1.6 (PD4)
/PBTN4: J8.4, U1.10 (XTAL2/PB7)
/PBTN5: J9.4, U1.12 (PD6)
/PLED1: R4.2, U1.3 (PD1)
/PLED2: R5.2, U1.5 (PD3)
/PLED3: R6.2, U1.9 (XTAL1/PB6)
/PLED4: R7.2, U1.11 (PD5)
/PLED5: R8.2, U1.13 (PD7)
/RESET: J4.5, R2.2, U1.1 (~RESET/PC6)
/SCK: J4.7, U1.19 (PB5)
GND: BZ1.2 (+), C1.2, C2.2, C3.2, DS1.1 (VSS), DS1.5 (R/W), DS1.16 (LED(-)), J1.5 (Shield), J2.4 (GND), J2.5 (Shield), J4.4, J4.6, J4.8, J4.10, J5.1, J5.3, J6.1, J6.3, J7.1, J7.3, J8.1, J8.3, J9.1, J9.3, Q1.3 (S), R3.2, RV1.1, SW1.2, SW2.2, SW3.2, U1.8 (GND), U1.22 (GND)
unnamed: DS1.15 (LED(+)), R1.1
unnamed: DS1.3 (VO), RV1.2
unnamed: J1.4 (GND), Q1.1 (D)
unnamed: J5.2, R4.1
unnamed: J6.2, R5.1
unnamed: J7.2, R6.1
unnamed: J8.2, R7.1
unnamed: J9.2, R8.1
VCC: C1.1, C2.1, C3.1, DS1.2 (VDD), J1.1 (VBUS), J2.1 (VBUS), J4.2, R1.2, R2.1, RV1.3, U1.7 (VCC), U1.20 (AVCC), U1.21 (AREF)

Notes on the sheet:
1602 text display
Atmega328p microcontroller
USB-B power input
Sockets for player buttons
Sound
Control buttons
USB-A output for signal lamp
In-circuit programmer socket

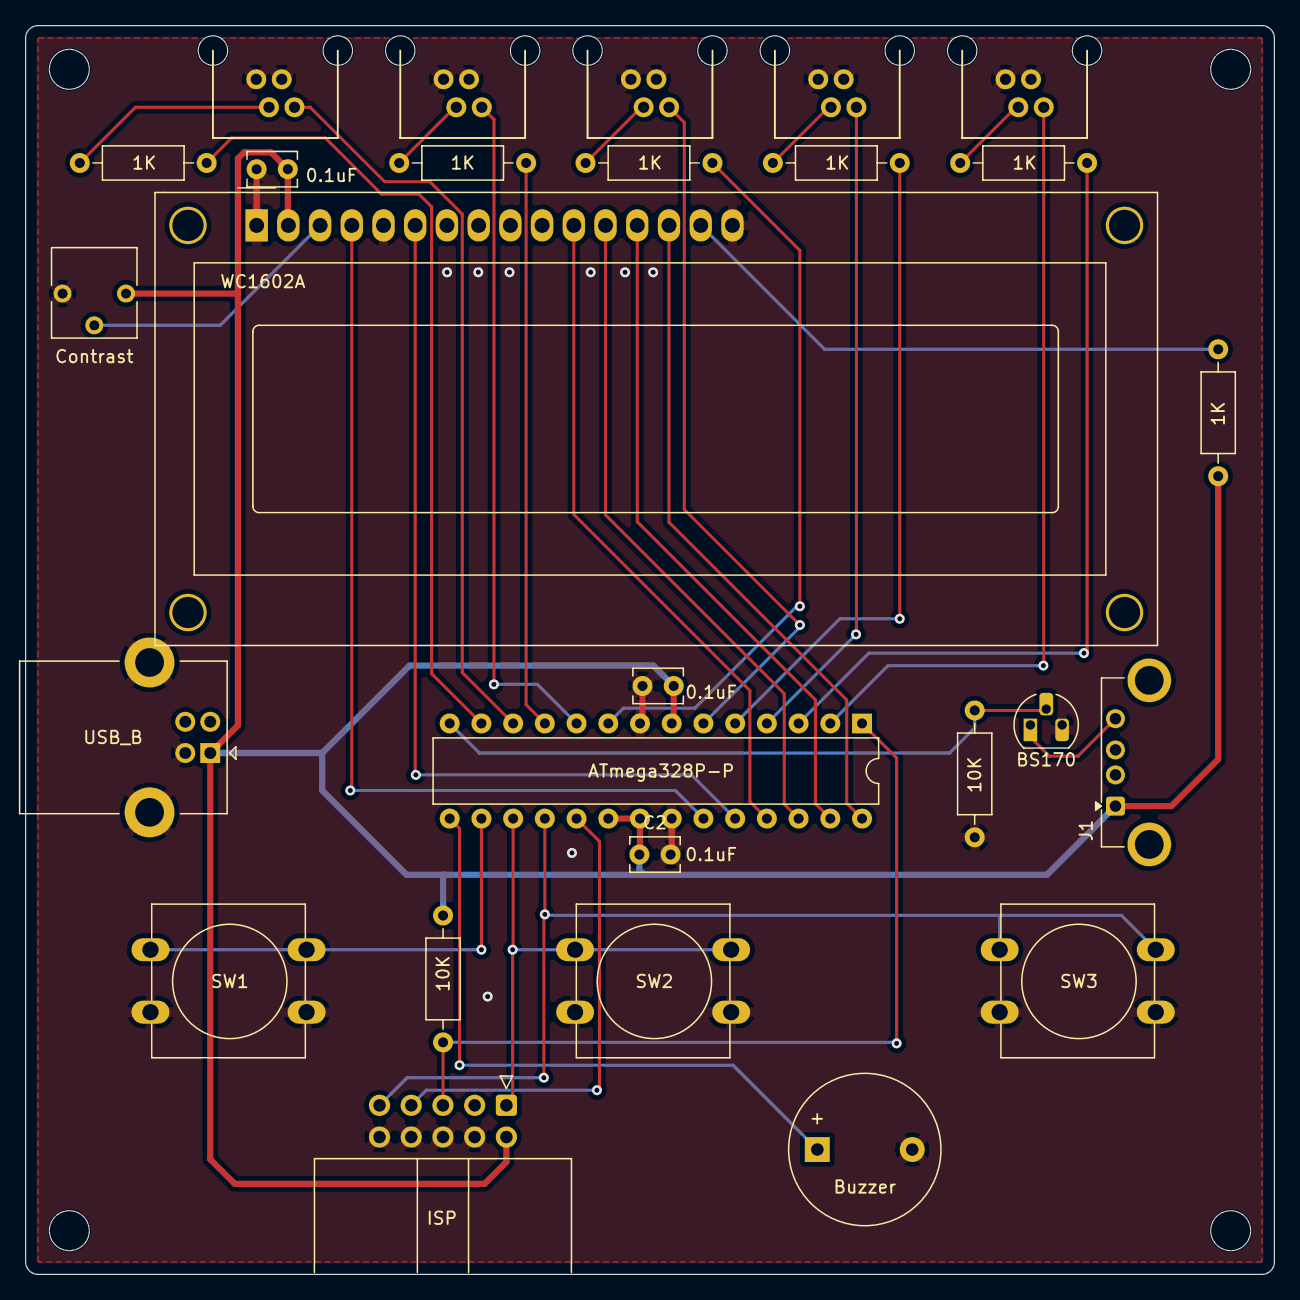
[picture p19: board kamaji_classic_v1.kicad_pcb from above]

Board: 2 copper layers, 100.0 x 100.0 mm, 27 parts (0 on the bottom side), 33 nets.

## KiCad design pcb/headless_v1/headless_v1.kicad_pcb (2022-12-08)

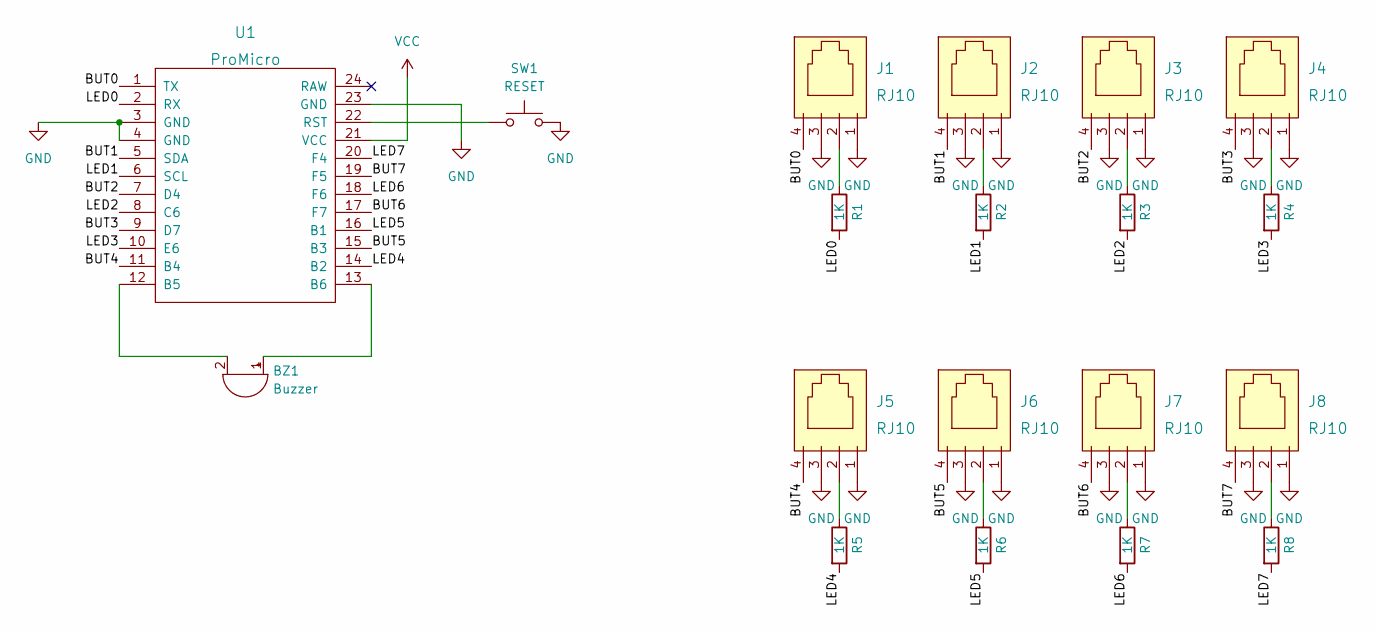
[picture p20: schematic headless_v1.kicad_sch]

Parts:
BZ1: Buzzer; Buzzer_12x9.5RM7.6
J1, J2, J3, J4, J5, J6, J7, J8: RJ10
R1, R2, R3, R4, R5, R6, R7, R8: 1K; R_Axial_DIN0207_L6.3mm_D2.5mm_P10.16mm_Horizontal
SW1: RESET; SW_PUSH_6mm
U1: ProMicro

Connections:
/BUT0: J1.4, U1.1 (TX)
/BUT1: J2.4, U1.5 (SDA)
/BUT2: J3.4, U1.7 (D4)
/BUT3: J4.4, U1.9 (D7)
/BUT4: J5.4, U1.11 (B4)
/BUT5: J6.4, U1.15 (B3)
/BUT6: J7.4, U1.17 (F7)
/BUT7: J8.4, U1.19 (F5)
/LED0: R1.2, U1.2 (RX)
/LED1: R2.2, U1.6 (SCL)
/LED2: R3.2, U1.8 (C6)
/LED3: R4.2, U1.10 (E6)
/LED4: R5.2, U1.14 (B2)
/LED5: R6.2, U1.16 (B1)
/LED6: R7.2, U1.18 (F6)
/LED7: R8.2, U1.20 (F4)
GND: J1.1, J1.3, J2.1, J2.3, J3.1, J3.3, J4.1, J4.3, J5.1, J5.3, J6.1, J6.3, J7.1, J7.3, J8.1, J8.3, SW1.2, U1.3 (GND), U1.4 (GND), U1.23 (GND)
unnamed: BZ1.1 (-), U1.13 (B6)
unnamed: BZ1.2 (+), U1.12 (B5)
unnamed: J1.2, R1.1
unnamed: J2.2, R2.1
unnamed: J3.2, R3.1
unnamed: J4.2, R4.1
unnamed: J5.2, R5.1
unnamed: J6.2, R6.1
unnamed: J7.2, R7.1
unnamed: J8.2, R8.1
unnamed: SW1.1, U1.22 (RST)
VCC: U1.21 (VCC)

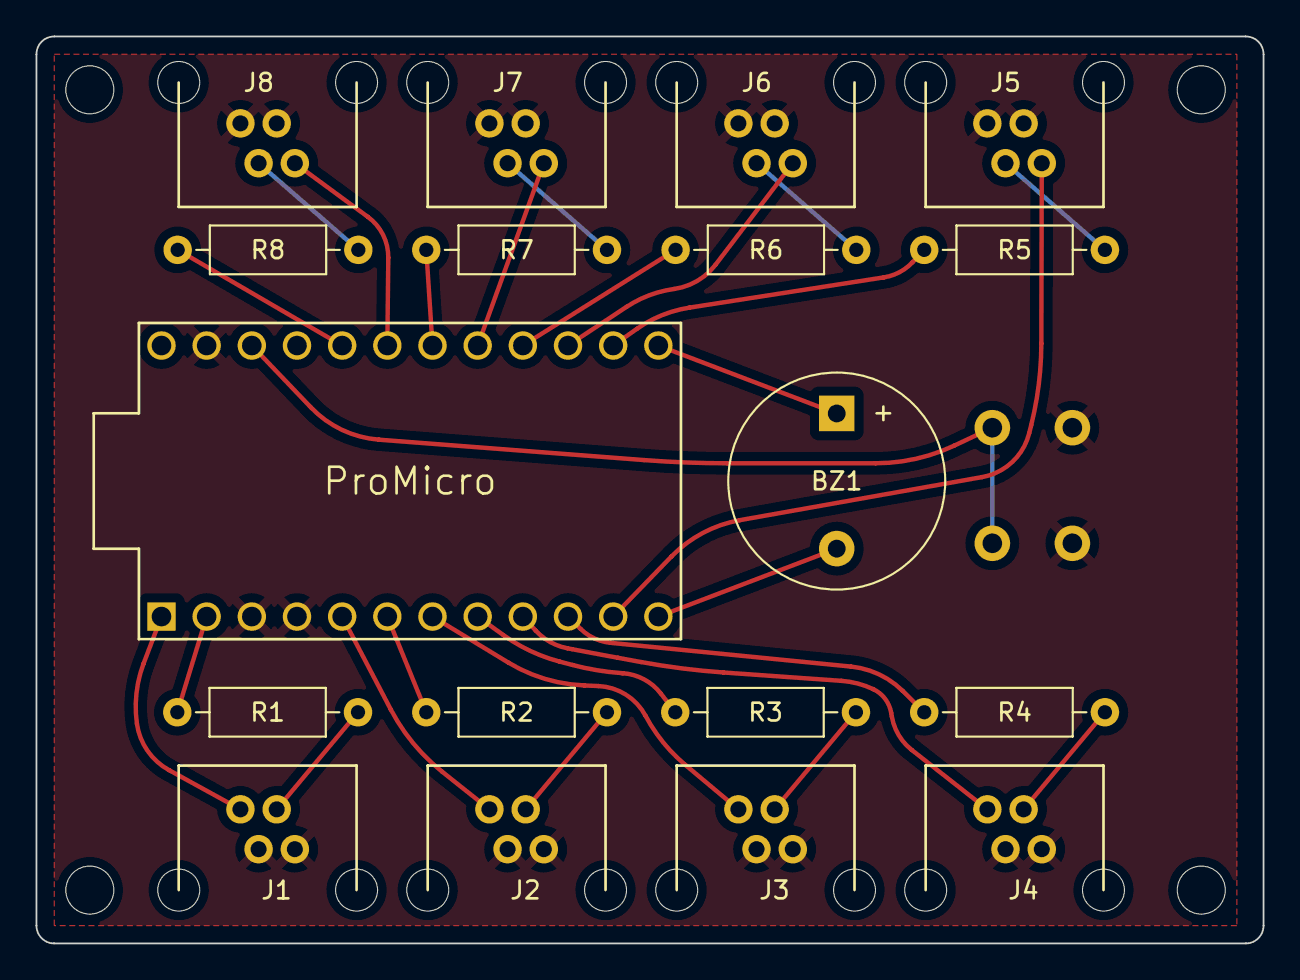
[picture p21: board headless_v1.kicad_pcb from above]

Board: 2 copper layers, 69.0 x 51.0 mm, 19 parts (1 on the bottom side), 28 nets.

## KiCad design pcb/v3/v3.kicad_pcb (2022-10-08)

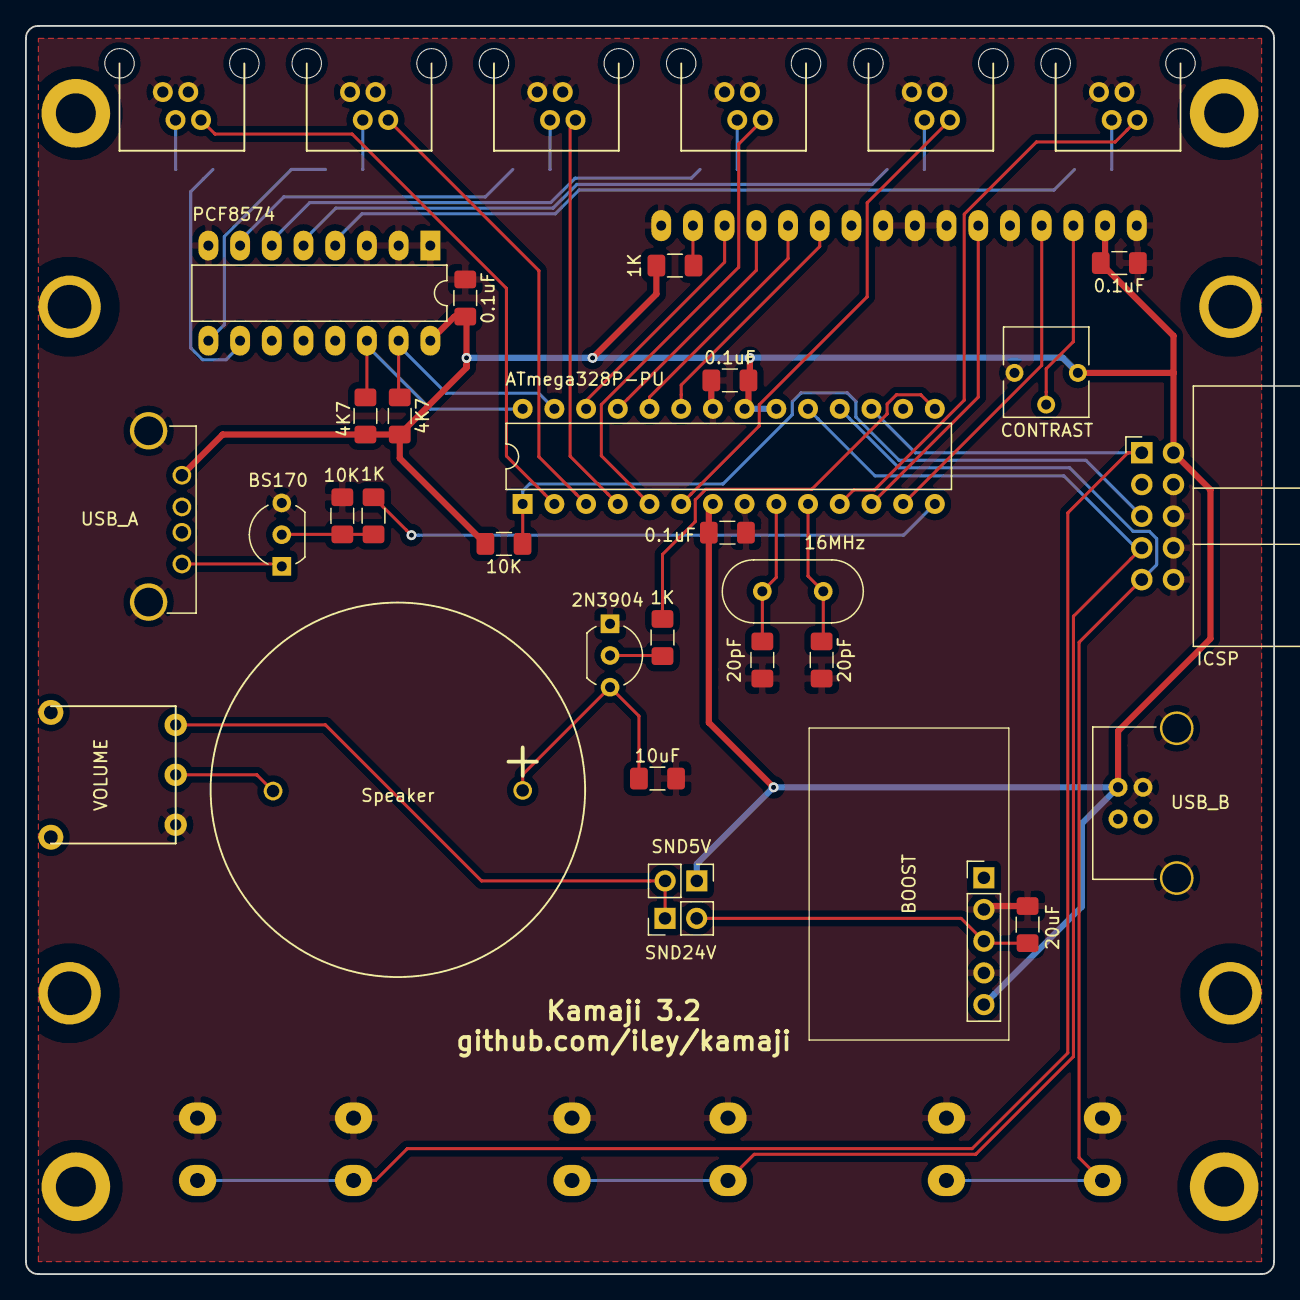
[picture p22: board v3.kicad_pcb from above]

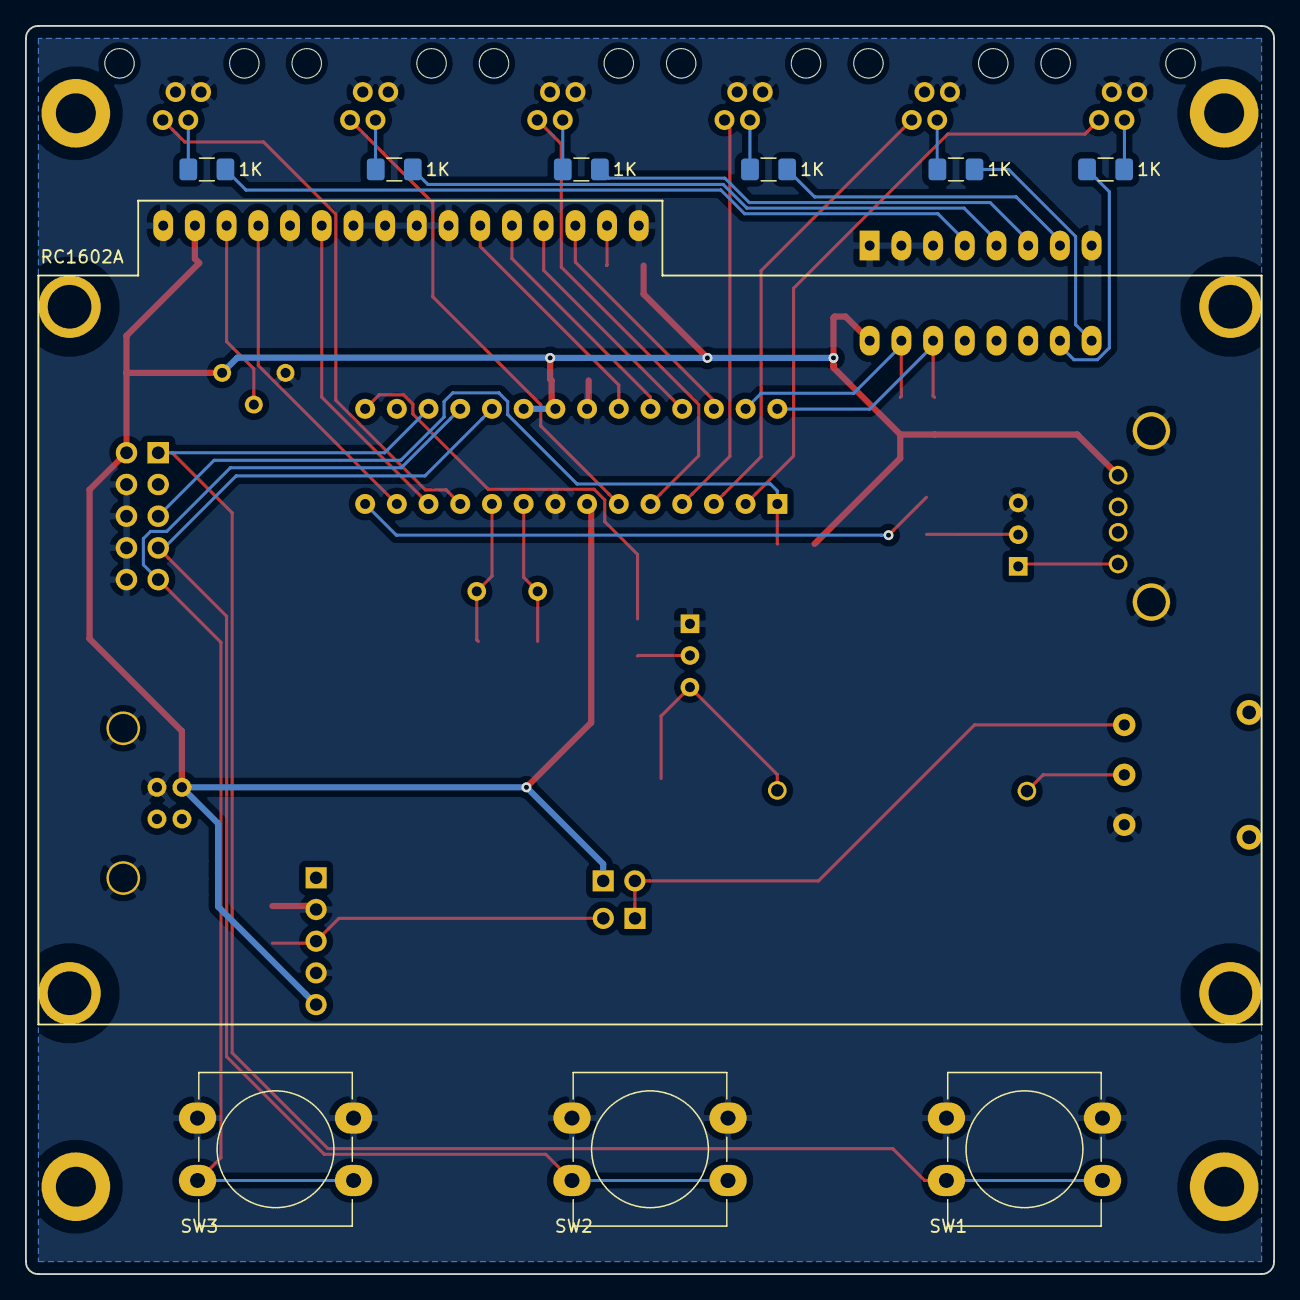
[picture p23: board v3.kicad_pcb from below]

Board: 2 copper layers, 100.0 x 100.0 mm, 45 parts (10 on the bottom side), 45 nets.

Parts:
C1, C4, C5, C7: 0.1uF; C_1206_3216Metric_Pad1.42x1.75mm_HandSolder
C2, C3: 20pF; C_1206_3216Metric_Pad1.42x1.75mm_HandSolder
C6: 20uF; C_1206_3216Metric_Pad1.42x1.75mm_HandSolder
C8: 10uF; C_1206_3216Metric_Pad1.42x1.75mm_HandSolder
J1, J3, J4, J5, J6, J7: RJ10
J2: ICSP; IDC-Header_2x05_P2.54mm_Horizontal
J8: BOOST; DD1718PA
J9: USB_B
J10: USB_A
JP1: SND24V; PinHeader_1x02_P2.54mm_Vertical
JP2: SND5V; PinHeader_1x02_P2.54mm_Vertical
LS1: Speaker; Buzzer_ARIO_98dB
Q2: 2N3904; TO-92_Inline_Wide
Q3: BS170; TO-92_Inline_Wide
R1, R2, R3, R5, R8, R9, R10, R12, R18: 1K; R_1206_3216Metric_Pad1.42x1.75mm_HandSolder
R4, R19: 10K; R_1206_3216Metric_Pad1.42x1.75mm_HandSolder
R6, R7: 4K7; R_1206_3216Metric_Pad1.42x1.75mm_HandSolder
RV1: CONTRAST; Potentiometer_Vishay_T73YP_Vertical
RV2: VOLUME; Potentiometer_Wheel_16mm
SW1: CTL1; Pushbutton_12mm
SW2: CTL2; Pushbutton_12mm
SW3: CTL3; Pushbutton_12mm
U1: ATmega328P-PU; DIP-28_W7.62mm
U2: PCF8574; DIP-16_W7.62mm_LongPads
U3: RC1602A; LCD2004
Y1: 16MHz; Crystal_HC49-U_Vertical

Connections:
+24V: C6.1, J8.3, JP1.2
/CBTN1: J2.1, SW1.1, U1.17
/CBTN2: J2.7, SW2.1, U1.19
/CBTN3: J2.9, SW3.1, U1.18
/LAMP: R18.2, U1.14
/LCD0: U1.23, U3.11
/LCD1: U1.24, U3.12
/LCD2: U1.25, U3.13
/LCD3: U1.26, U3.14
/LCDE: U1.12, U3.6
/LCDRS: U1.13, U3.4
/PBTN1: J1.4, U1.11
/PBTN2: J3.4, U1.6
/PBTN3: J4.4, U1.5
/PBTN4: J5.4, U1.4
/PBTN5: J6.4, U1.3
/PBTN6: J7.4, U1.2
/PLED1: R1.2, U2.4
/PLED2: R2.2, U2.5
/PLED3: R3.2, U2.6
/PLED4: R5.2, U2.7
/PLED5: R8.2, U2.9
/PLED6: R9.2, U2.10
/RST: J2.5, R4.2, U1.1
/SCL: R7.2, U1.28, U2.14
/SDA: R6.2, U1.27, U2.15
/SPK: R12.1, U1.15
/XTAL1: C2.2, U1.9, Y1.1
/XTAL2: C3.2, U1.10, Y1.2
GND: C1.2, C2.1, C3.1, C4.2, C5.2, C6.2, C7.2, C8.1, J1.1, J1.3, J2.4, J2.6, J2.8, J2.10, J3.1, J3.3, J4.1, J4.3, J5.1, J5.3, J6.1, J6.3, J7.1, J7.3, J8.2, J8.4, J9.4, J9.5, J10.5, Q2.1, Q3.3, R19.2, RV1.1, RV2.1, SW1.2, SW2.2, SW3.2, U1.8, U1.22, U2.1, U2.2, U2.3, U2.8, U3.1, U3.5, U3.7, U3.8, U3.9, U3.10, U3.16
unnamed: C8.2, LS1.1, Q2.3
unnamed: J1.2, R1.1
unnamed: J3.2, R2.1
unnamed: J4.2, R3.1
unnamed: J5.2, R5.1
unnamed: J6.2, R8.1
unnamed: J7.2, R9.1
unnamed: J10.4, Q3.1
unnamed: JP1.1, JP2.2, RV2.3
unnamed: LS1.2, RV2.2
unnamed: Q2.2, R12.2
unnamed: Q3.2, R18.1, R19.1
unnamed: R10.1, U3.15
unnamed: RV1.2, U3.3
VCC: C1.1, C4.1, C5.1, C7.1, J2.2, J8.5, J9.1, J10.1, JP2.1, R4.1, R6.1, R7.1, R10.2, RV1.3, U1.7, U1.20, U1.21, U2.16, U3.2

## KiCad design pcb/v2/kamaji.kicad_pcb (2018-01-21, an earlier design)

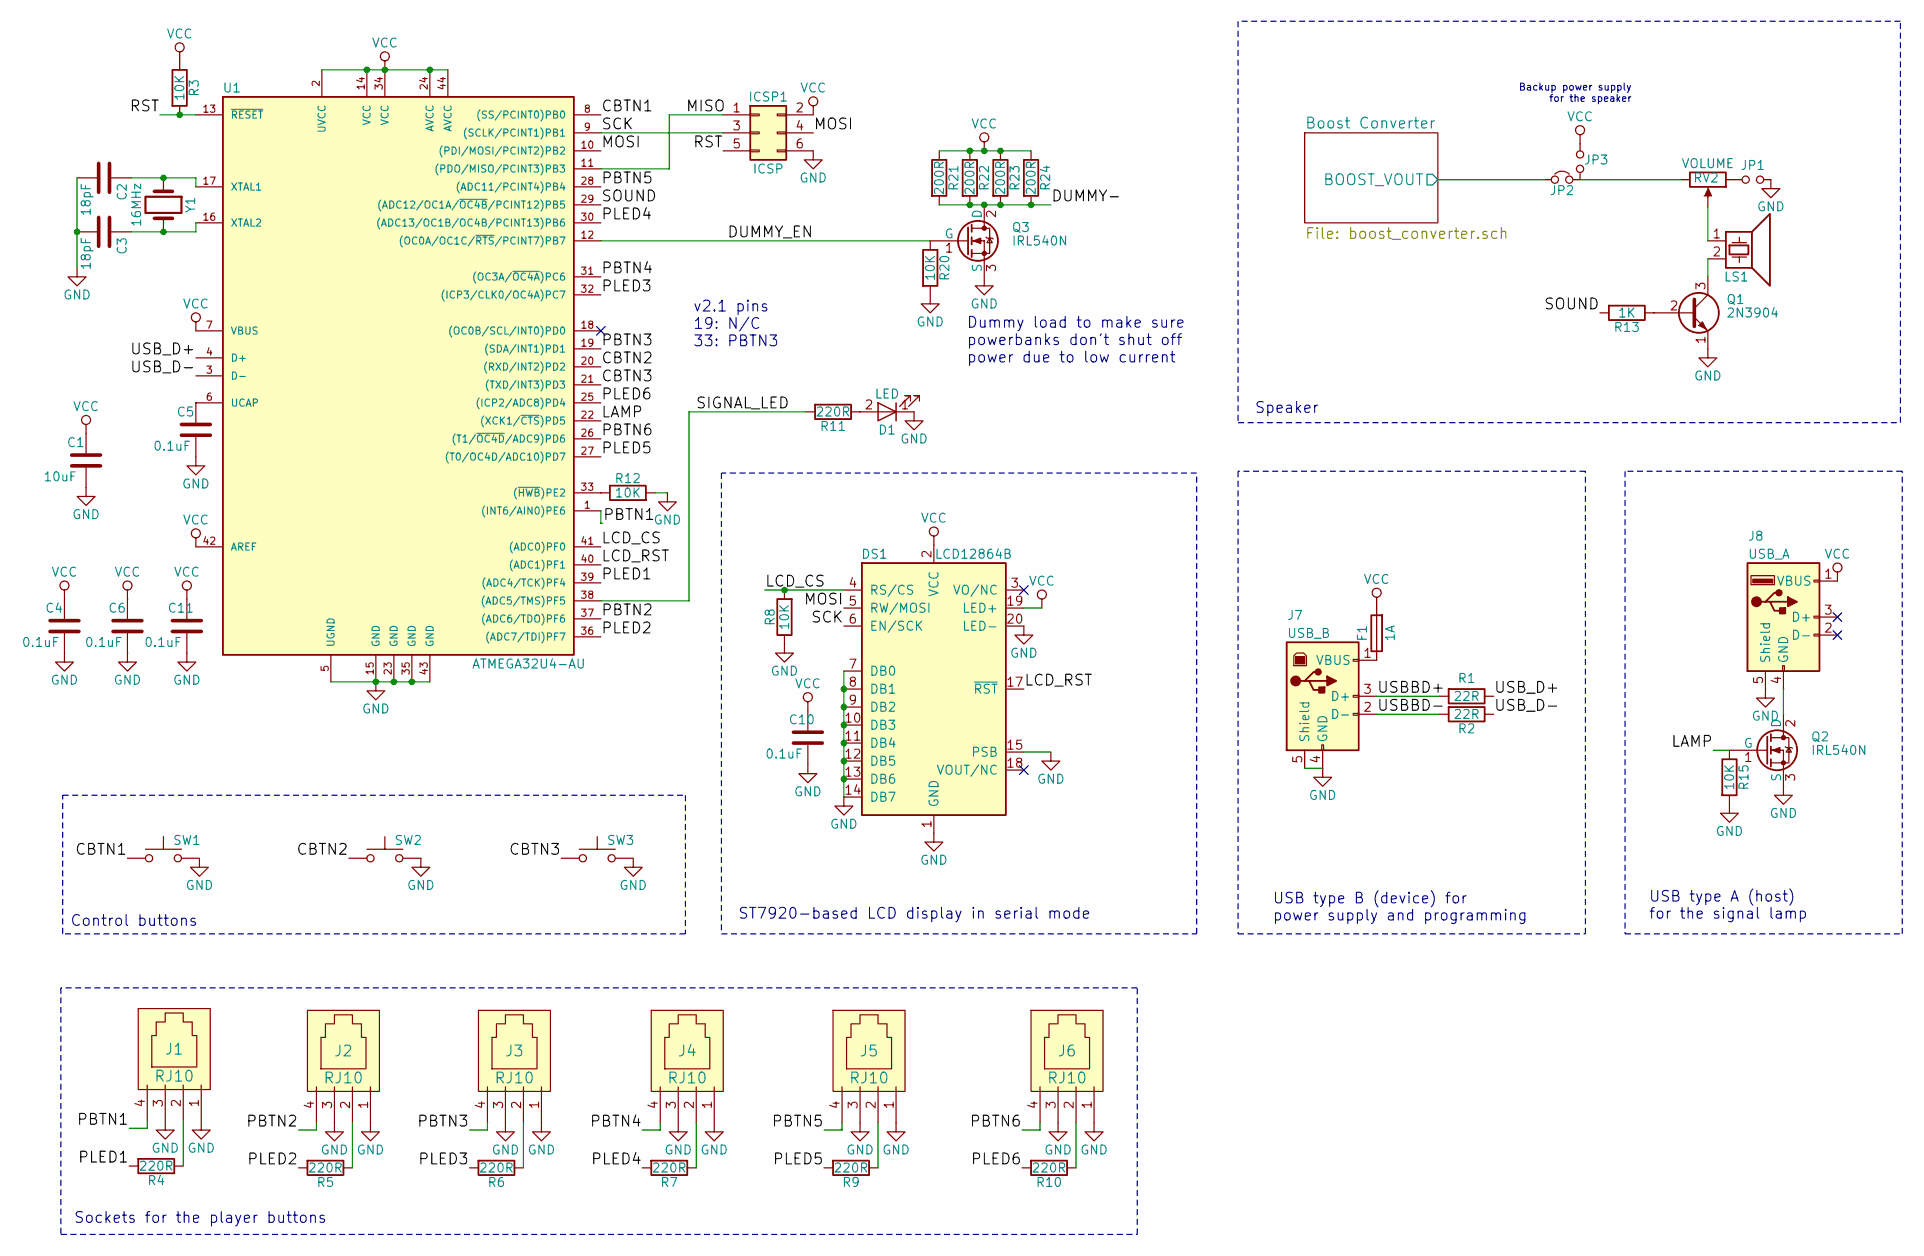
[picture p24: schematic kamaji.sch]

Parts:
C1: 10uF; C_1206_HandSoldering
C2, C3: 18pF; C_1206_HandSoldering
C4, C5, C6, C10, C11: 0.1uF; C_1206_HandSoldering
D1: LED; LED_D5.0mm
DS1: LCD12864B; LCD12864
F1: 1A; R_1812_HandSoldering
ICSP1: ICSP; ATmega_ISP_6pin
J1, J2, J3, J4, J5, J6: RJ10
J7: USB_B
J8: USB_A
JP1: Jumper_NO_Small; Pin_Header_Straight_1x02_Pitch2.54mm
JP2: Jumper_NC_Small; Pin_Header_Straight_1x02_Pitch2.54mm
JP3: SoundVcc2; Pin_Header_Straight_1x02_Pitch2.54mm
LS1: Speaker_Crystal; Buzzer_ARIO_98dB
Q1: 2N3904; TO-92_Molded_Narrow
Q2, Q3: IRL540N; TO-220-3_Horizontal
R1, R2: 22R; R_1206_HandSoldering
R3, R8, R12, R15, R20: 10K; R_1206_HandSoldering
R4, R5, R6, R7, R9, R10, R11: 220R; R_1206_HandSoldering
R13: 1K; R_1206_HandSoldering
R21, R22, R23, R24: 200R; R_Axial_DIN0207_L6.3mm_D2.5mm_P10.16mm_Horizontal
RV2: VOLUME; Potentiometer_Wheel_16mm
SW1, SW2, SW3: SW_Push; SW_PUSH-12mm_Wuerth-430476085716
U1: ATMEGA32U4-AU; TQFP-44_10x10mm_Pitch0.8mm
Y1: 16MHz; Crystal_HC49-U_Vertical

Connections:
/Boost Converter/BOOST_VOUT: JP2.1; also elsewhere on the board
/CBTN1: SW1.1, U1.8 ((SS/PCINT0)PB0)
/CBTN2: SW2.1, U1.20 ((RXD/INT2)PD2)
/CBTN3: SW3.1, U1.21 ((TXD/INT3)PD3)
/DUMMY-: Q3.2 (D), R21.2, R22.2, R23.2, R24.2
/DUMMY_EN: Q3.1 (G), R20.1, U1.12 ((OC0A/OC1C/~RTS~/PCINT7)PB7)
/LAMP: Q2.1 (G), R15.1, U1.22 ((XCK1/~CTS~)PD5)
/LCD_CS: DS1.4 (RS/CS), R8.2, U1.41 ((ADC0)PF0)
/LCD_RST: DS1.17 (~RST~), U1.40 ((ADC1)PF1)
/MISO: ICSP1.1, U1.11 ((PDO/MISO/PCINT3)PB3)
/MOSI: DS1.5 (RW/MOSI), ICSP1.4, U1.10 ((PDI/MOSI/PCINT2)PB2)
/PBTN1: J1.4, U1.1 ((INT6/AIN0)PE6)
/PBTN2: J2.4, U1.37 ((ADC6/TDO)PF6)
/PBTN3: J3.4, U1.19 ((SDA/INT1)PD1)
/PBTN4: J4.4, U1.31 ((OC3A/~OC4A~)PC6)
/PBTN5: J5.4, U1.28 ((ADC11/PCINT4)PB4)
/PBTN6: J6.4, U1.26 ((T1/~OC4D~/ADC9)PD6)
/PLED1: R4.2, U1.39 ((ADC4/TCK)PF4)
/PLED2: R5.2, U1.36 ((ADC7/TDI)PF7)
/PLED3: R6.2, U1.32 ((ICP3/CLK0/OC4A)PC7)
/PLED4: R7.2, U1.30 ((ADC13/OC1B/OC4B/PCINT13)PB6)
/PLED5: R9.2, U1.27 ((T0/OC4D/ADC10)PD7)
/PLED6: R10.2, U1.25 ((ICP2/ADC8)PD4)
/RST: ICSP1.5, R3.2, U1.13 (~RESET~)
/SCK: DS1.6 (EN/SCK), ICSP1.3, U1.9 ((SCLK/PCINT1)PB1)
/SIGNAL_LED: R11.2, U1.38 ((ADC5/TMS)PF5)
/SOUND: R13.2, U1.29 ((ADC12/OC1A/~OC4B~/PCINT12)PB5)
/USBBD+: J7.3 (D+), R1.2
/USBBD-: J7.2 (D-), R2.2
/USB_D+: R1.1, U1.4 (D+)
/USB_D-: R2.1, U1.3 (D-)
GND: C1.2, C2.2, C3.2, C4.2, C5.2, C6.2, C10.2, C11.2, D1.1 (K), DS1.1 (GND), DS1.7 (DB0), DS1.8 (DB1), DS1.9 (DB2), DS1.10 (DB3), DS1.11 (DB4), DS1.12 (DB5), DS1.13 (DB6), DS1.14 (DB7), DS1.15 (PSB), DS1.20 (LED-), ICSP1.6, J1.1, J1.3, J2.1, J2.3, J3.1, J3.3, J4.1, J4.3, J5.1, J5.3, J6.1, J6.3, J7.4 (GND), J7.5 (Shield), J8.5 (Shield), JP1.2, Q1.1 (E), Q2.3 (S), Q3.3 (S), R8.1, R12.2, R15.2, R20.2, SW1.2, SW2.2, SW3.2, U1.5 (UGND), U1.15 (GND), U1.23 (GND), U1.35 (GND), U1.43 (GND); also elsewhere on the board
unnamed: C2.1, U1.17 (XTAL1), Y1.1
unnamed: C3.1, U1.16 (XTAL2), Y1.2
unnamed: C5.1, U1.6 (UCAP)
unnamed: D1.2 (A), R11.1
unnamed: F1.1, J7.1 (VBUS)
unnamed: J1.2, R4.1
unnamed: J2.2, R5.1
unnamed: J3.2, R6.1
unnamed: J4.2, R7.1
unnamed: J5.2, R9.1
unnamed: J6.2, R10.1
unnamed: J8.4 (GND), Q2.2 (D)
unnamed: JP1.1, RV2.1
unnamed: JP2.2, JP3.2, RV2.3
unnamed: LS1.1, RV2.2
unnamed: LS1.2, Q1.3 (C)
unnamed: Q1.2 (B), R13.1
unnamed: R12.1, U1.33 ((~HWB~)PE2)
VCC: C1.1, C4.1, C6.1, C10.1, C11.1, DS1.2 (VCC), DS1.19 (LED+), F1.2, ICSP1.2, J8.1 (VBUS), JP3.1, R3.1, R21.1, R22.1, R23.1, R24.1, U1.2 (UVCC), U1.7 (VBUS), U1.14 (VCC), U1.24 (AVCC), U1.34 (VCC), U1.42 (AREF), U1.44 (AVCC); also elsewhere on the board

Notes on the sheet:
USB type B (device) for power supply and programming
USB type A (host) for the signal lamp
Backup power supply for the speaker
Dummy load to make sure powerbanks don't shut off power due to low current
ST7920-based LCD display in serial mode
Speaker
Sockets for the player buttons
Control buttons
v2.1 pins 19: N/C 33: PBTN3

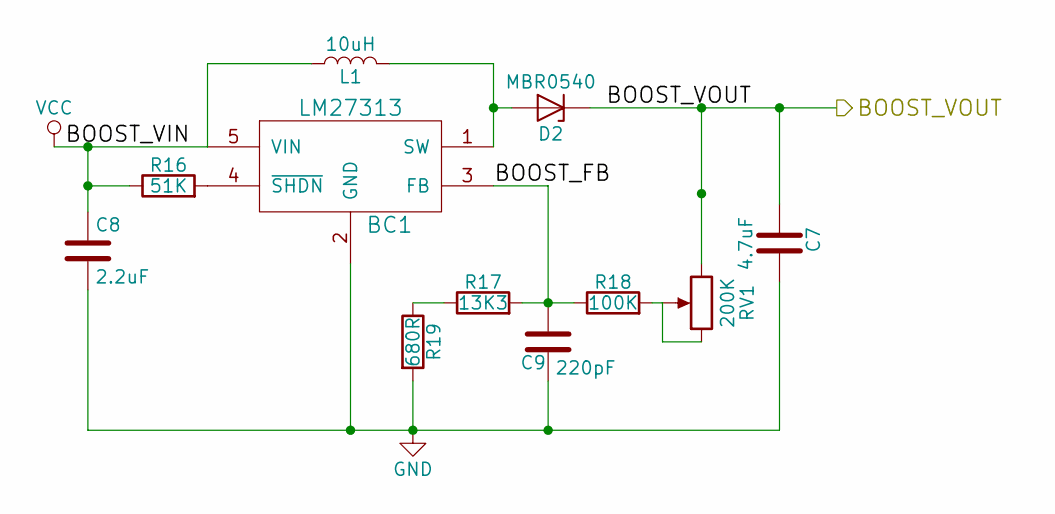
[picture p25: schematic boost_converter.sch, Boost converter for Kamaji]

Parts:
BC1: LM27313; SOT-23-5_HandSoldering
C7: 4.7uF; C_1206_HandSoldering
C8: 2.2uF; C_1206_HandSoldering
C9: 220pF; C_1206_HandSoldering
D2: MBR0540; D_SOD-323_HandSoldering
L1: 10uH; Inductor_PIS2408_SMD
R16: 51K; R_1206_HandSoldering
R17: 13K3; R_1206_HandSoldering
R18: 100K; R_1206_HandSoldering
R19: 680R; R_1206_HandSoldering
RV1: 200K; Potentiometer_Trimmer_Bourns_3339P_Horizontal

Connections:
/Boost Converter/BOOST_FB: BC1.3 (FB), C9.1, R17.2, R18.1
/Boost Converter/BOOST_VOUT: C7.1, D2.1 (K), RV1.3; also elsewhere on the board
GND: BC1.2 (GND), C7.2, C8.2, C9.2, R19.2; also elsewhere on the board
unnamed: BC1.1 (SW), D2.2 (A), L1.2
unnamed: BC1.4 (~SHDN), R16.2
unnamed: R17.1, R19.1
unnamed: R18.2, RV1.1, RV1.2
VCC: BC1.5 (VIN), C8.1, L1.1, R16.1; also elsewhere on the board

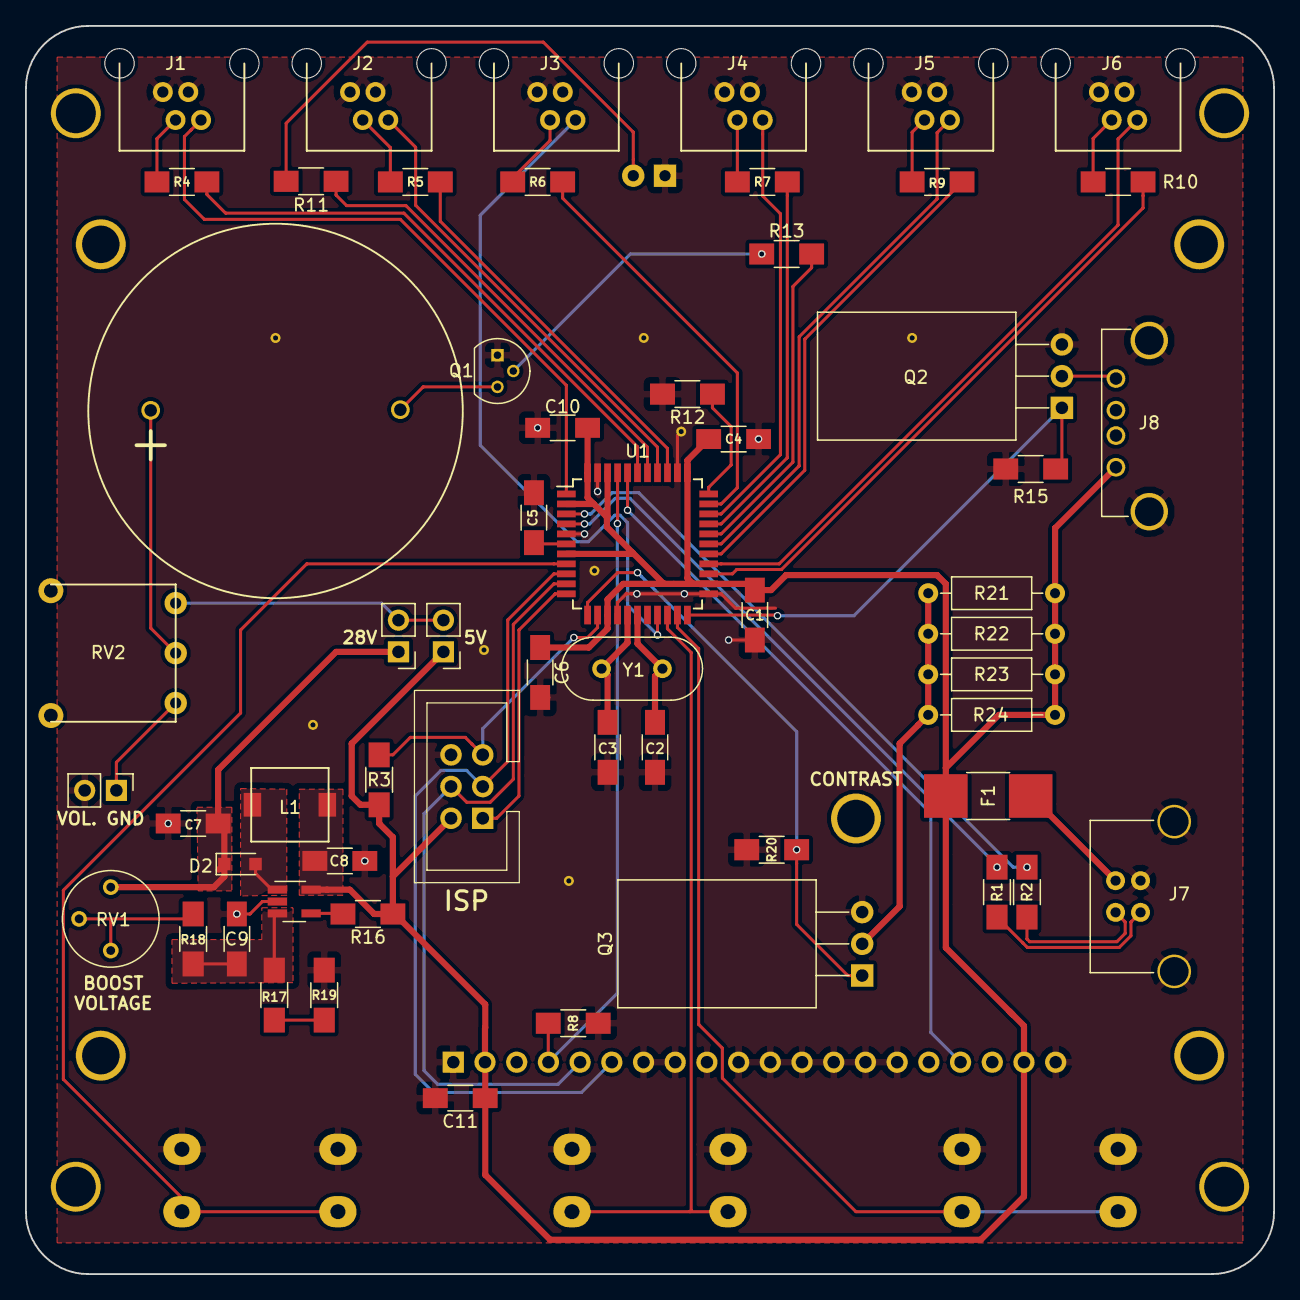
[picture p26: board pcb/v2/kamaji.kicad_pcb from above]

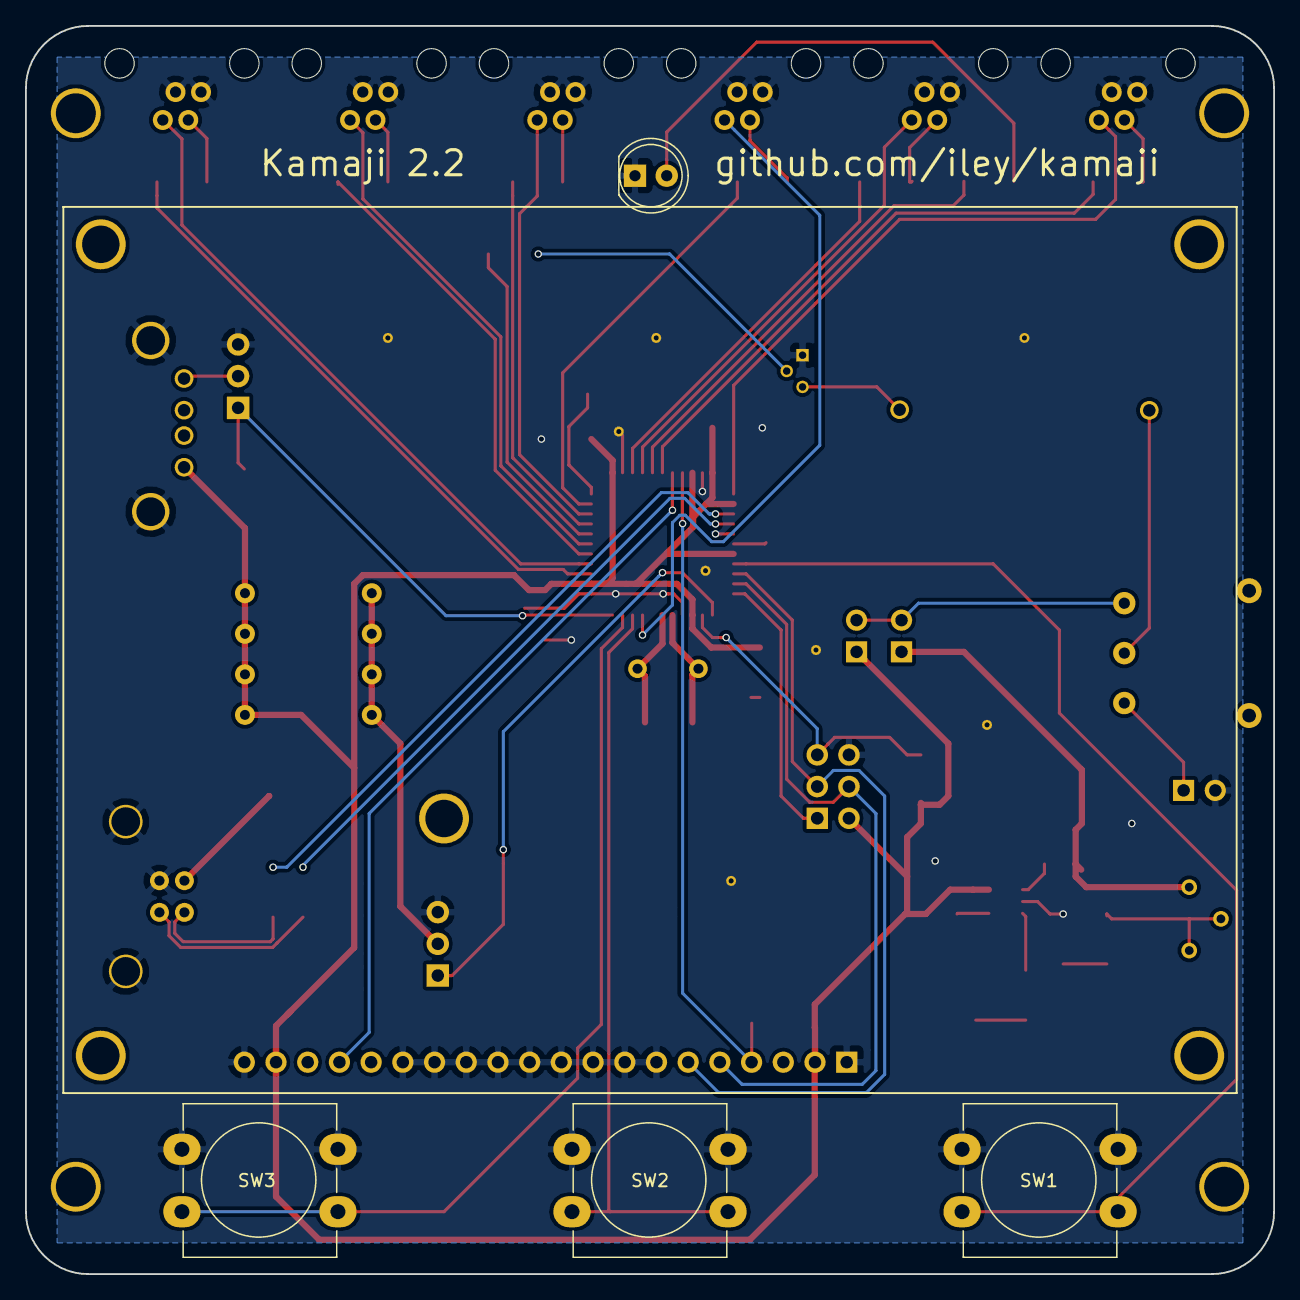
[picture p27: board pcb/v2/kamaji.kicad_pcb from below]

Board: 2 copper layers, 100.0 x 100.0 mm, 71 parts (5 on the bottom side), 56 nets.

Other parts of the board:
VIA**: Via_0.8mm
VIA**#2, VIA**#3, VIA**#4, VIA**#5, VIA**#6, VIA**#7, VIA**#8: Via_0.8mm

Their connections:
GND: VIA**.1, VIA**#2.1, VIA**#3.1, VIA**#4.1, VIA**#5.1, VIA**#6.1, VIA**#7.1, VIA**#8.1; also elsewhere on the board

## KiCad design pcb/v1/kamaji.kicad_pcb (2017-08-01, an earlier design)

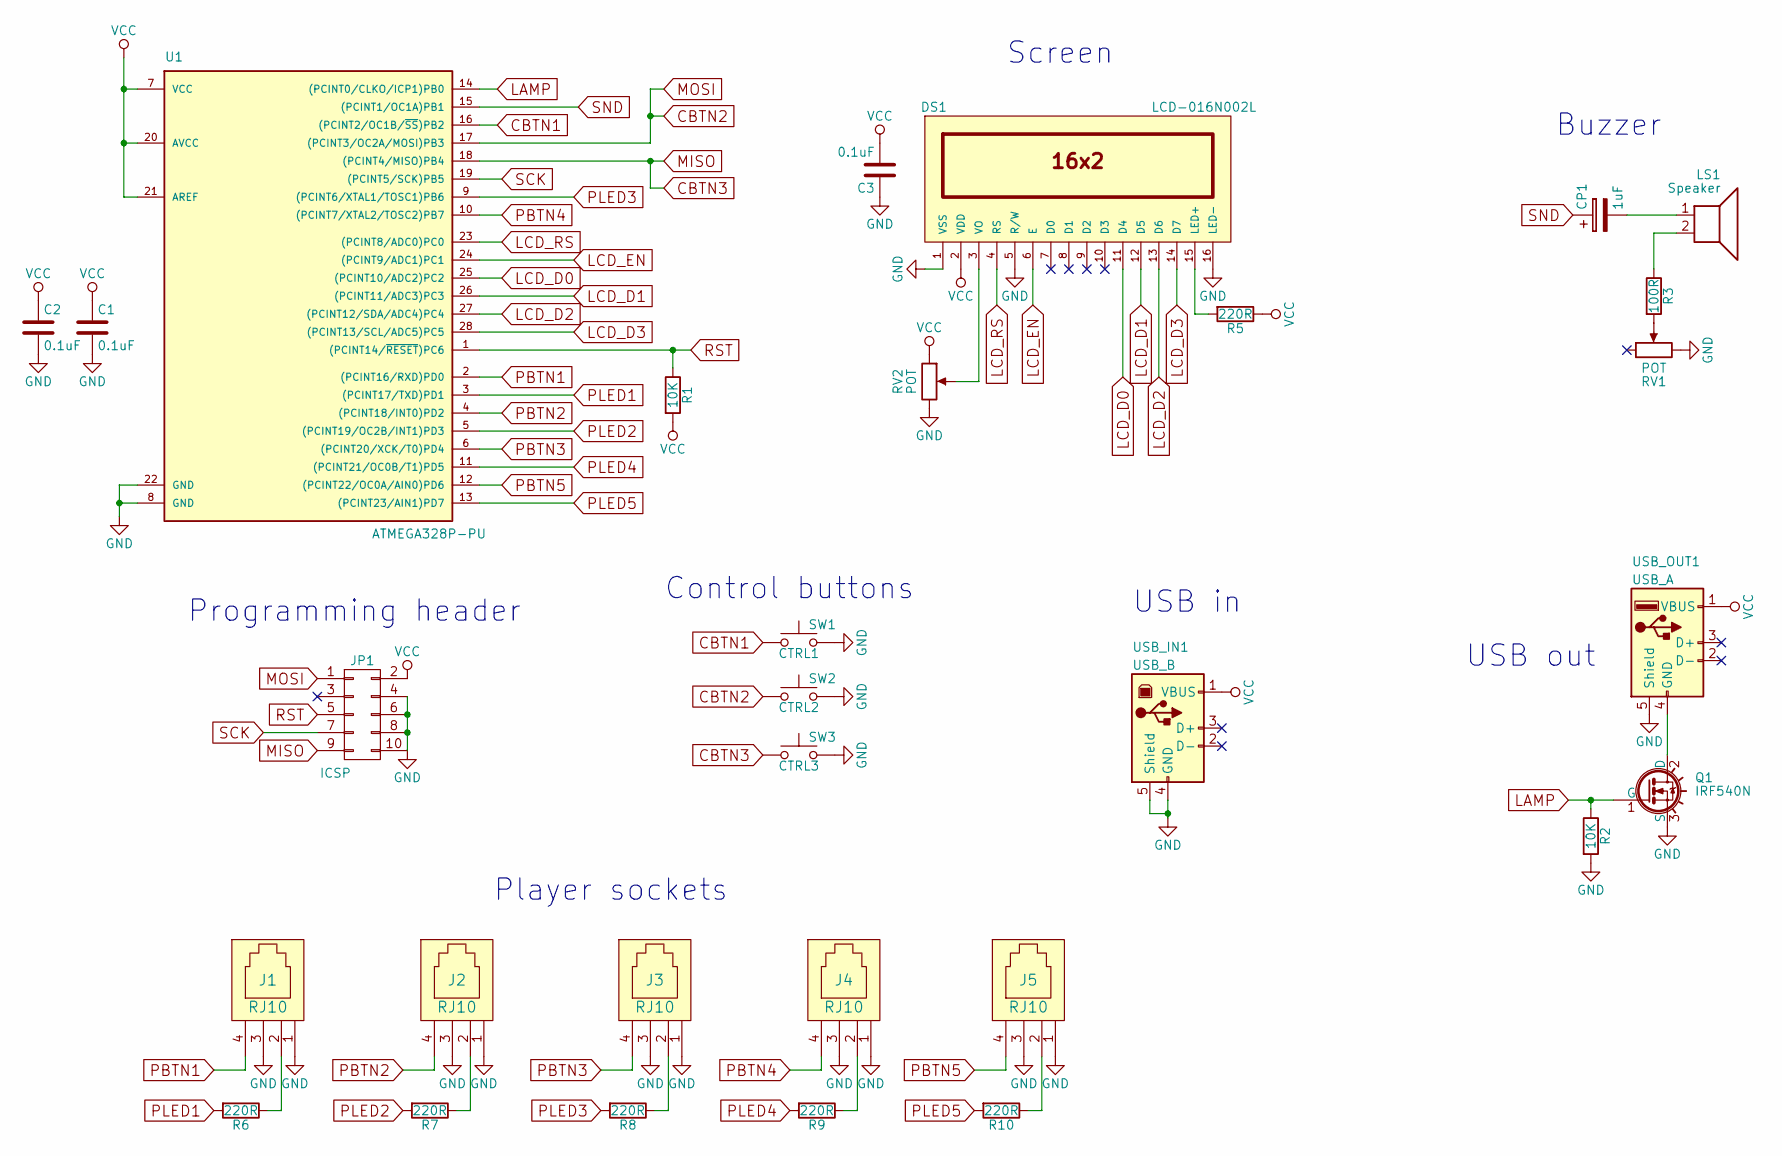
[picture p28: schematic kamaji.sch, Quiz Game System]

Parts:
C1, C2, C3: 0.1uF; C_Disc_D3.8mm_W2.6mm_P2.50mm
CP1: 1uF; CP_Radial_D4.0mm_P1.50mm
DS1: LCD-016N002L; WC1602A
J1, J2, J3, J4, J5: RJ10
JP1: ICSP; IDC_Header_Straight_10pins
LS1: Speaker; AL-30P
Q1: IRF540N; TO-220_Horizontal
R1, R2: 10K; R_Axial_DIN0207_L6.3mm_D2.5mm_P10.16mm_Horizontal
R3: 100R; R_Axial_DIN0207_L6.3mm_D2.5mm_P10.16mm_Horizontal
R5, R6, R7, R8, R9, R10: 220R; R_Axial_DIN0207_L6.3mm_D2.5mm_P10.16mm_Horizontal
RV1, RV2: POT; Potentiometer_Triwood_RM-065
SW1: CTRL1; SW_PUSH_6mm_h8.5mm
SW2: CTRL2; SW_PUSH_6mm_h8.5mm
SW3: CTRL3; SW_PUSH_6mm_h8.5mm
U1: ATMEGA328P-PU; DIP-28_W7.62mm
USB_IN1: USB_B
USB_OUT1: USB_A

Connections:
CBTN1: SW1.1, U1.16 ((PCINT2/OC1B/~SS~)PB2)
CBTN2: JP1.1, SW2.1, U1.17 ((PCINT3/OC2A/MOSI)PB3)
CBTN3: JP1.9, SW3.1, U1.18 ((PCINT4/MISO)PB4)
GND: C1.2, C2.2, C3.1, DS1.1 (VSS), DS1.5 (R/W), DS1.16 (LED-), J1.1, J1.3, J2.1, J2.3, J3.1, J3.3, J4.1, J4.3, J5.1, J5.3, JP1.4, JP1.6, JP1.8, JP1.10, Q1.3 (S), R2.2, RV1.3, RV2.3, SW1.2, SW2.2, SW3.2, U1.8 (GND), U1.22 (GND), USB_IN1.4 (GND), USB_IN1.5 (Shield), USB_OUT1.5 (Shield)
LAMP: Q1.1 (G), R2.1, U1.14 ((PCINT0/CLKO/ICP1)PB0)
LCD_D0: DS1.11 (D4), U1.25 ((PCINT10/ADC2)PC2)
LCD_D1: DS1.12 (D5), U1.26 ((PCINT11/ADC3)PC3)
LCD_D2: DS1.13 (D6), U1.27 ((PCINT12/SDA/ADC4)PC4)
LCD_D3: DS1.14 (D7), U1.28 ((PCINT13/SCL/ADC5)PC5)
LCD_EN: DS1.6 (E), U1.24 ((PCINT9/ADC1)PC1)
LCD_RS: DS1.4 (RS), U1.23 ((PCINT8/ADC0)PC0)
unnamed: CP1.2, LS1.1
unnamed: DS1.3 (VO), RV2.2
unnamed: DS1.15 (LED+), R5.2
unnamed: J1.2, R6.1
unnamed: J2.2, R7.1
unnamed: J3.2, R8.1
unnamed: J4.2, R9.1
unnamed: J5.2, R10.1
unnamed: LS1.2, R3.1
unnamed: Q1.2 (D), USB_OUT1.4 (GND)
unnamed: R3.2, RV1.2
PBTN1: J1.4, U1.2 ((PCINT16/RXD)PD0)
PBTN2: J2.4, U1.4 ((PCINT18/INT0)PD2)
PBTN3: J3.4, U1.6 ((PCINT20/XCK/T0)PD4)
PBTN4: J4.4, U1.10 ((PCINT7/XTAL2/TOSC2)PB7)
PBTN5: J5.4, U1.12 ((PCINT22/OC0A/AIN0)PD6)
PLED1: R6.2, U1.3 ((PCINT17/TXD)PD1)
PLED2: R7.2, U1.5 ((PCINT19/OC2B/INT1)PD3)
PLED3: R8.2, U1.9 ((PCINT6/XTAL1/TOSC1)PB6)
PLED4: R9.2, U1.11 ((PCINT21/OC0B/T1)PD5)
PLED5: R10.2, U1.13 ((PCINT23/AIN1)PD7)
RST: JP1.5, R1.1, U1.1 ((PCINT14/~RESET~)PC6)
SCK: JP1.7, U1.19 ((PCINT5/SCK)PB5)
SND: CP1.1, U1.15 ((PCINT1/OC1A)PB1)
VCC: C1.1, C2.1, C3.2, DS1.2 (VDD), JP1.2, R1.2, R5.1, RV2.1, U1.7 (VCC), U1.20 (AVCC), U1.21 (AREF), USB_IN1.1 (VBUS), USB_OUT1.1 (VBUS)

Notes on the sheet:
Buzzer
Player sockets
USB out
Control buttons
Programming header
USB in
Screen

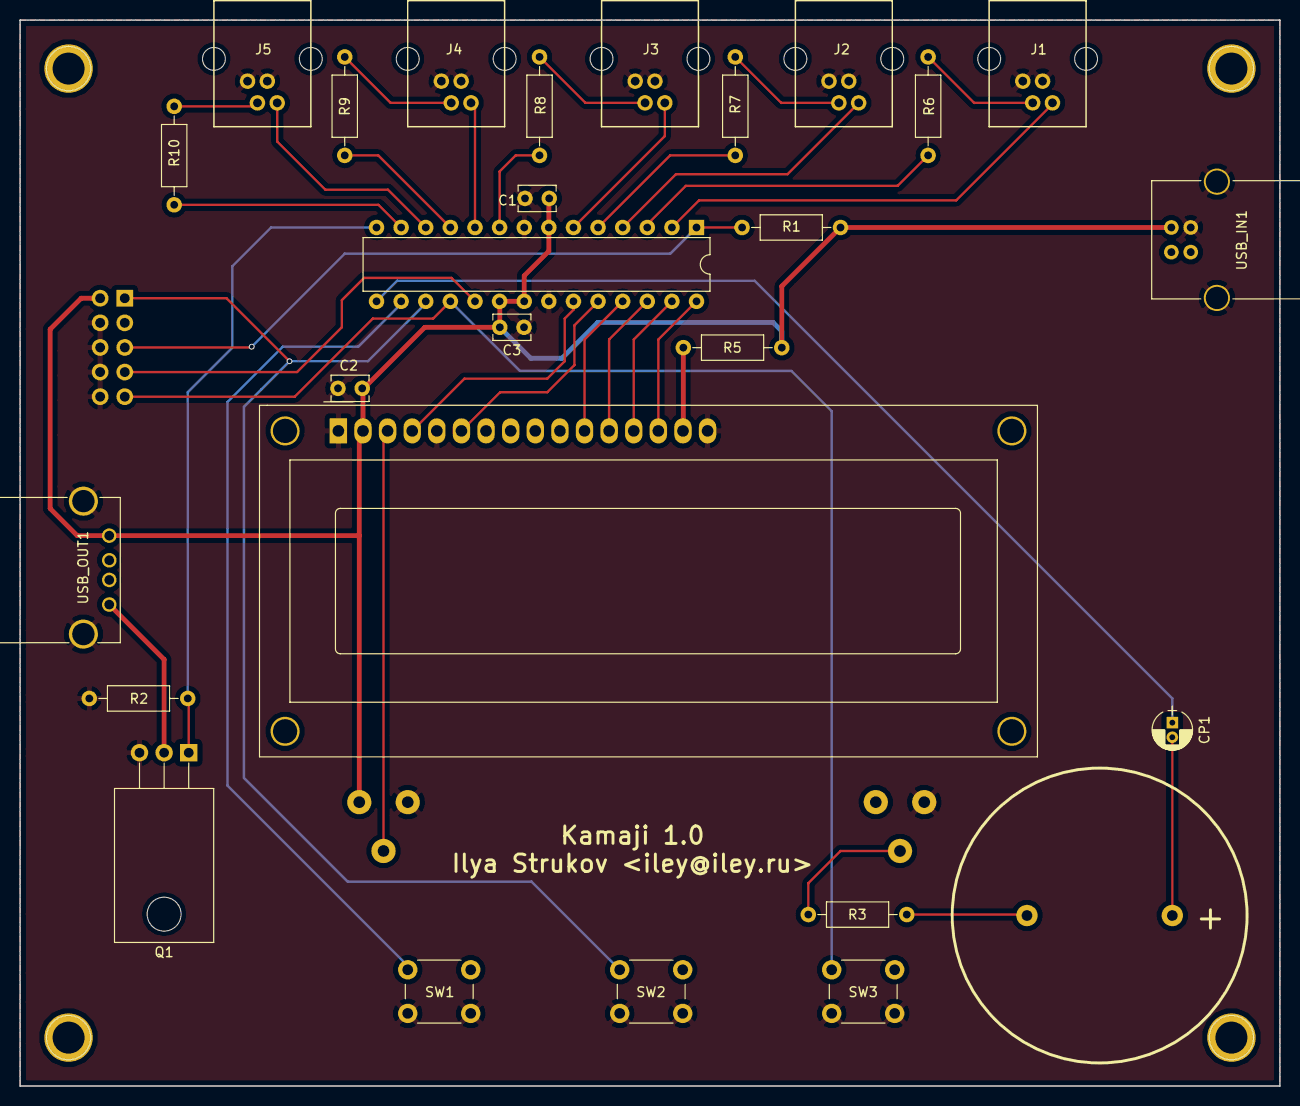
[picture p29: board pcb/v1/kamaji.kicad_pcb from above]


Board: 2 copper layers, 130.0 x 110.0 mm, 30 parts (3 on the bottom side), 36 nets.

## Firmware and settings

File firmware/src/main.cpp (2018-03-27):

#include <Arduino.h>
#include <string.h>

#include "lamp.h"
#include "lcd.h"
#include "main.h"
#include "mode.h"
#include "pitches.h"
#include "xpins.h"
#include "strlen.h"

// How long the two buttons need to be held for a reset.
const unsigned long kResetDelayMs = 2000;
// Button debounce delay in milliseconds.
const unsigned long kDebounceMs = 100;

// Pin numbers for buttons and LEDs are defined in the corresponding config:
// config_v[01].h
DECLARE_KBUTTON_PINS();
DECLARE_KLED_PINS();
DECLARE_KSPEAKER_PIN();
DECLARE_LCD();

SelectMode selectMode;

// Selected game mode.
Mode *mode = &selectMode;

// Button state, true means pressed.
bool buttons[BUTTON_COUNT] = { false };
// Button state before the latest update.
bool buttonsBefore[BUTTON_COUNT] = { false };
// For each button, time when it was last pressed.
unsigned long lastPressedMs[BUTTON_COUNT] = {0};

char caption[2 * kDisplayCols + 1];
char score[2 * kDisplayCols + 1];
char info[2 * kDisplayCols + 1];
char lastLeft[2 * kDisplayCols + 1];
char lastRight[2 * kDisplayCols + 1];
char lastMiddle[2 * kDisplayCols + 1];
char lastCaption[2 * kDisplayCols + 1];
char lastScore[2 * kDisplayCols + 1];
char lastInfo[2 * kDisplayCols + 1];

// Whether the reset buttons are being held.
bool resetStarted = false;
// Time when the reset buttons were pushed.
unsigned long resetStartTime;

void setup() {
  for (const int buttonPin : kButtonPins) {
    xPinMode(buttonPin, INPUT_PULLUP);
  }
  for (const int ledPin : kLedPins) {
    xPinMode(ledPin, OUTPUT);
    xDigitalWrite(ledPin, LOW);
  }
  xPinMode(kSpeakerPin, OUTPUT);

  initLamp();
  initLcd(&lcd);
  mode->init();
  tone(kSpeakerPin, NOTE_A7, 300/*ms*/);
}

void updateScreenAndLeds() {
  switchLamp(mode->getLampState());
  for (int i = BUTTON_PLAYER_1; i <= LAST_PLAYER_BUTTON; i++) {
    xDigitalWrite(kLedPins[i], mode->getLedState(i) ? HIGH : LOW);
  }
  if (mode->isEssential()) {
    return;
  }
  caption[0] = '\0';
  mode->getCaption(caption, sizeof(caption), kDisplayCols);
  score[0] = '\0';
  mode->getScore(score, sizeof(score), kDisplayCols);
  info[0] = '\0';
  mode->getInfo(info, sizeof(info), kDisplayCols);
  const char* left = mode->getLabel(BUTTON_RESET);
  const char* right = mode->getLabel(BUTTON_START);
  const char* middle = mode->getLabel(BUTTON_CONTROL_2);
  if (strcmp(lastCaption, caption) != 0 ||
      strcmp(lastScore, score) != 0 ||
      strcmp(lastLeft, left) != 0 ||
      strcmp(lastRight, right) != 0 ||
      strcmp(lastMiddle, middle) != 0 ||
      strcmp(lastInfo, info)) {
    lcd.clear();
    if (kDisplayRows == 2) {
      lcd.print(mode->preferShowScore() ? score : caption);
    } else {
      lcd.print(score);
      lcd.setCursor(0, 2);
      lcd.print(caption);
      lcd.setCursor(0, 3);
      lcd.print(info);
    }
    lcd.setCursor(/*col=*/0, /*row=*/kDisplayRows == 2 ? 1 : 4);
    // Print button functions on the lower line of the screen.
    lcd.print(left);
    const int spaces = kDisplayCols - strlen_utf(left) - strlen_utf(right) - strlen_utf(middle);
    for (int i = 0; i < spaces / 2; ++i) {
      lcd.print(' ');
    }
    lcd.print(middle);
    for (int i = 0; i < (spaces + 1) / 2; ++i) {
      lcd.print(' ');
    }
    lcd.print(right);
    flushLcd(&lcd);  // Redraw the screen.
    strncpy(lastMiddle, middle, sizeof(lastMiddle));
    strncpy(lastLeft, left, sizeof(lastLeft));
    strncpy(lastRight, right, sizeof(lastRight));
    strncpy(lastCaption, caption, sizeof(lastCaption));
    strncpy(lastScore, score, sizeof(lastScore));
    strncpy(lastInfo, info, sizeof(lastInfo));
  }
}

void loop() {
  unsigned long now = millis();
  // Read all buttons and save their state in a global array.
  for (int i = 0; i < BUTTON_COUNT; ++i) {
    buttonsBefore[i] = buttons[i];
    // Ignore the button state changes if it was pressed less than kDebounceMs
    // milliseconds ago to account for contact bouncing.
    if (now - lastPressedMs[i] > kDebounceMs) {
      // The buttons pins are active LOW.
      if (xDigitalRead(kButtonPins[i]) == LOW) {
        buttons[i] = true;
        lastPressedMs[i] = now;
      } else {
        buttons[i] = false;
      }
    }
  }
  if (buttons[BUTTON_RESET] && buttons[BUTTON_START]) {
    if (resetStarted && now - resetStartTime > kResetDelayMs) {
      mode = &selectMode;
      mode->init();
    } else if (!resetStarted) {
      resetStarted = true;
      resetStartTime = now;
    }
  } else {
    resetStarted = false;
  }
  mode->update();
  updateScreenAndLeds();
}

bool isPlayerPressed(int playerId) {
  return buttons[playerId] && !buttonsBefore[playerId];
}

bool isControlPressed(int buttonId) {
  return buttons[buttonId] && !buttonsBefore[buttonId];
}

void playStartSound() {
  tone(kSpeakerPin, NOTE_DS6, 300/*ms*/); 
}

void playTimeSound() {
  tone(kSpeakerPin, NOTE_DS6, 1000/*ms*/);
}

void playResetSound() {
  tone(kSpeakerPin, NOTE_D6, 1000/*ms*/);
}

void playPlayerSound() {
  tone(kSpeakerPin, NOTE_F6, 300/*ms*/);
}

void playTimerSound() {
  tone(kSpeakerPin, NOTE_F6, 100/*ms*/);
}

void playCorrectSound() {
  tone(kSpeakerPin, NOTE_C6, 300/*ms*/);
}

void playFalseStartSound() {
  tone(kSpeakerPin, NOTE_G6, 500/*ms*/);
}

void playAttentionSound() {
  tone(kSpeakerPin, NOTE_F6, 300/*ms*/);
}

void setMode(Mode *newMode) {
  mode = newMode;
  mode->init();
}

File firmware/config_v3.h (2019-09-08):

#ifndef CONFIG_V3_H
#define CONFIG_V3_H

#define USE_LAMP 1
#define USE_PCF8574_LEDS 1

// All available buttons.
enum {
  BUTTON_PLAYER_1,
  BUTTON_PLAYER_2,
  BUTTON_PLAYER_3,
  BUTTON_PLAYER_4,
  BUTTON_PLAYER_5,
  BUTTON_PLAYER_6,

  BUTTON_CONTROL_1,
  BUTTON_CONTROL_2,
  BUTTON_CONTROL_3,

  BUTTON_COUNT = BUTTON_CONTROL_3 + 1,

  BUTTON_RESET = BUTTON_CONTROL_1,
  BUTTON_START = BUTTON_CONTROL_3,

  FIRST_PLAYER_BUTTON = BUTTON_PLAYER_1,
  LAST_PLAYER_BUTTON = BUTTON_PLAYER_6,
  PLAYER_COUNT = BUTTON_PLAYER_5 - BUTTON_PLAYER_1 + 1
};

// Pin numbers for each button, indexed by the enum values above.
// Players:
// PBTN1: PD5 - pin 5
// PBTN2: PD4 - pin 4
// PBTN3: PD3 - pin 3
// PBTN4: PD2 - pin 2
// PBTN5: PD1 - pin 1
// PBTN6: PD0 - pin 0
// Controls:
// CBTN1: PB3 - pin 11
// CBTN2: PB5 - pin 13
// CBTN3: PB4 - pin 12
#define DECLARE_KBUTTON_PINS()    \
  const int kButtonPins[] = {     \
    5, 4, 3, 2, 1, 0, /* players */ \
    11, 13, 12,       /* control */ \
  }

// Not used in this version.
#define DECLARE_KLED_PINS() \
  const int kLedPins[] = {10, 10, 10, 10, 10, 10}

#define DECLARE_KSPEAKER_PIN()  \
  const int kSpeakerPin = 9

// Lamp: PB0 - pin 8
#define DECLARE_KLAMP_PIN()  \
  const int kLampPin = 8

#endif  // CONFIG_V3_H

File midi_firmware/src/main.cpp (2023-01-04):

#include <Arduino.h>
#include <MIDIUSB.h>
#include <pitchToNote.h>
#include <pitchToFrequency.h>
#include <toneAC.h>

#include "pushbutton.h"

enum {
  MIDI_CHANNEL_BUTTONS = 0,
  MIDI_CHANNEL_LEDS = 1,
  MIDI_CHANNEL_BUZZER = 2,
};

const int kPlayerCount = 8;

const uint8_t kButtonPins[kPlayerCount] = {
  1, 2, 4, 6,
  8, 14, 18, 20,
};

const uint8_t kLedPins[kPlayerCount] = {
  0, 3, 5, 7,
  16, 15, 19, 21,
};

const byte kPlayerPitches[kPlayerCount] = {
  pitchC1, pitchD1b, pitchD1, pitchE1b,
  pitchE1, pitchF1, pitchG1b, pitchG1,
};

PushButton buttons[kPlayerCount];

void setup() {
  unsigned long now = millis();
  for (int i = 0; i < kPlayerCount; i++) {
    buttons[i].init(kButtonPins[i]);
    pinMode(kLedPins[i], OUTPUT);
  }
}

inline byte playerIndexToPitch(int index) {
  return kPlayerPitches[index];
}

int pitchToPlayerIndex(byte pitch) {
  for (int i = 0; i < kPlayerCount; i++) {
    if (kPlayerPitches[i] == pitch) {
      return i;
    }
  }
  return -1;
}

void noteOn(byte channel, byte pitch, byte velocity) {
  midiEventPacket_t noteOn = {0x09, 0x90 | channel, pitch, velocity};
  MidiUSB.sendMIDI(noteOn);
}

void noteOff(byte channel, byte pitch, byte velocity) {
  midiEventPacket_t noteOff = {0x08, 0x80 | channel, pitch, velocity};
  MidiUSB.sendMIDI(noteOff);
}

void handleNoteOn(byte channel, byte pitch, byte velocity) {
  if (channel == MIDI_CHANNEL_LEDS) {
    int index = pitchToPlayerIndex(pitch);
    if (index != -1) {
      digitalWrite(kLedPins[index], HIGH);
    }
  } else if (channel == MIDI_CHANNEL_BUZZER) {
    toneAC(pitchFrequency[pitch]);
  }
}

void handleNoteOff(byte channel, byte pitch, byte velocity) {
  if (channel == MIDI_CHANNEL_LEDS) {
    int index = pitchToPlayerIndex(pitch);
    if (index != -1) {
      digitalWrite(kLedPins[index], LOW);
    }
  } else if (channel == MIDI_CHANNEL_BUZZER) {
    toneAC(0);
  }
}

void loop() {
  midiEventPacket_t rx = MidiUSB.read();
  switch (rx.header) {
    case 0x09:
      handleNoteOn(/*channel=*/rx.byte1 & 0xF, /*pitch=*/rx.byte2, /*velocity=*/rx.byte3);
      break;
    case 0x08:
      handleNoteOff(/*channel=*/rx.byte1 & 0xF, /*pitch=*/rx.byte2, /*velocity=*/rx.byte3);
      break;
  }

  for (int i = 0; i < kPlayerCount; i++) {
    switch (buttons[i].poll()) {
      case PushButton::NO_CHANGE:
        break;
      case PushButton::PUSH_DOWN:
        noteOn(MIDI_CHANNEL_BUTTONS, playerIndexToPitch(i), 127);
        break;
      case PushButton::PUSH_UP:
        noteOff(MIDI_CHANNEL_BUTTONS, playerIndexToPitch(i), 0);
        break;
    }
  }
  MidiUSB.flush();
}

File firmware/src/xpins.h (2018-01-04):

#ifndef KAMAJI_XPINS_H
#define KAMAJI_XPINS_H

#include <Arduino.h>

constexpr uint8_t kXpinsBase = 50;

// ATMega328p XTAL pins.
constexpr uint8_t kPinPB6 = kXpinsBase + 0;
constexpr uint8_t  kPinPB7 = kXpinsBase + 1;
// ATMega32u4 pins.
constexpr uint8_t kPinPE2 = kXpinsBase + 2;  // HWB (enables bootloader).
constexpr uint8_t kPinPD5 = kXpinsBase + 3;  // Used as LED on Arduino.

#define USE_XPINS_HACK (defined(XPINS_ATMEGA328P) || defined(XPINS_ATMEGA32U4))

#if USE_XPINS_HACK

// Wrappers for Arduino's digitalRead, digitalWrite and pinMode with support for
// PB6 (XTAL1) and PB7 (XTAL2).
int xDigitalRead(uint8_t pin);
void xDigitalWrite(uint8_t pin, uint8_t val);
void xPinMode(uint8_t pin, uint8_t mode);

#else

#define xDigitalRead digitalRead
#define xDigitalWrite digitalWrite
#define xPinMode pinMode

#endif  //USE_XPINS_HACK

#endif  // KAMAJI_XPINS_H

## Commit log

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2017-06-22 add the missing button mapping
    [main.cpp]
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2017-07-04 reverse the player order
    [main.cpp]
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2017-07-07 fix a bug in fastestPlayer()
    [main.cpp]
2017-07-14 revert the randomization stuff
    [main.cpp]
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2017-07-16 start the pcb layout
    [kamaji.kicad_pcb, kamaji.sch]
2017-07-16 some progress on the schematics
    [kamaji.sch]
2017-07-16 first version of the schematic
    [kamaji.sch]
2017-07-17 Printed version of roof
    [bottom.scad, roof.scad]
2017-07-17 get rid of the shift register
    [kamaji.sch]
2017-07-19 add current-limiting resistors for player LEDs
    [kamaji.sch]
2017-07-20 roughly place components on the PCB
    [kamaji.kicad_pcb, kamaji.sch]
2017-07-20 minor changes to the schematic
    [kamaji.sch]
2017-07-20 change component placement for easier routing
    [kamaji.kicad_pcb]
2017-07-20 a few more component moves
    [kamaji.kicad_pcb]
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2017-07-20 first attempt at PCB routing
    [kamaji.kicad_pcb]
2017-07-21 a few minor changes to the PCB layout
    [kamaji.kicad_pcb]
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2017-07-21 center the player sockets
    [kamaji.kicad_pcb]
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2017-07-21 move a few tracks
    [kamaji.kicad_pcb]
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2017-07-22 change mounting hole sizes, move labels around
    [kamaji.kicad_pcb]
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2017-07-22 final touches to the PCB design
    [kamaji.kicad_pcb]
2017-07-22 replace TIP120 with a MOSFET, drive the speaker directly
    [kamaji.kicad_pcb, kamaji.sch]
2017-07-22 fix mounting holes
    [kamaji.kicad_pcb]
2017-07-22 use a polarized capacitor for the speaker
    [kamaji.kicad_pcb, kamaji.sch]
2017-07-22 fix the capacitor labels
    [kamaji.kicad_pcb, kamaji.sch]
2017-07-22 rotate the ICSP socket for easier access
    [kamaji.kicad_pcb]
2017-07-22 switch to a 10-pin ICSP connector
    [kamaji.kicad_pcb, kamaji.sch]
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2017-07-23 minor changes to the PCB
    [kamaji.kicad_pcb]
2017-07-23 change a capacitor value
    [kamaji.kicad_pcb, kamaji.sch]
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2017-07-29 remove the extra trace going to one of the buttons
    [kamaji.kicad_pcb]
2017-07-30 start laying out a new, smaller PCB
    [kamaji.kicad_pcb, kamaji.sch]
2017-07-30 lay out the 1.1 PCB
    [kamaji.kicad_pcb, kamaji.sch]
2017-07-30 move the speaker footprint
    [kamaji.kicad_pcb]
2017-08-01 rename pcb to pcb1.1 to make the 1.0 version available at master
    [kamaji.kicad_pcb, kamaji.sch]
2017-08-01 bring back the 1.0 pcb
    [kamaji.kicad_pcb, kamaji.sch]
2017-08-07 pcb v1.1: re-route crystal, a few other adjustments
    [kamaji.kicad_pcb]
2017-08-07 move the crystal and a usb socket
    [kamaji.kicad_pcb]
2017-08-09 fix formatting, remove an old TODO
    [main.cpp]
2017-08-11 make xDigitalWrite a bit shorter
    [main.cpp]
2017-08-11 fix a typo in xPinMode
    [main.cpp]
2017-08-11 add a script for setting correct FUSE values
2017-08-12 sketch an LCD support 3D model
    [lcd_support_v1.scad]
2017-08-14 set LCD support dimensions
    [lcd_support_v1.scad]
2017-08-14 Bottom model with low fence
    [bottom.scad]
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2017-08-14 minor adjustments to bottom.scad
    [bottom.scad]
2017-08-14 change the nut trap drawing code
    [bottom.scad]
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2017-08-17 Correct measures
    [bottom.scad]
2017-08-17 enclosure top: minor adjustments
    [bottom.scad]
2017-08-18 Fix for 2 mm
    [bottom.scad]
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2017-08-18 dimensions of the top enclosure
    [bottom.scad]
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2017-08-18 Fix TODOs, low border by 1.5
    [bottom.scad, buttons.scad]
2017-08-22 rename files in 3d/
    [buttons_v1.scad, enclosure_v1.scad]
2017-08-22 remove old 3d model
    [roof.scad]
2017-08-23 adjust the buttons diameter
    [buttons_v1.scad]
2017-08-23 adjust buttons diameter again
    [buttons_v1.scad]
2017-08-23 Revert "adjust buttons diameter again"
    This reverts commit 4d08f24b96e21f3ca8a92ca791474b8490ea357c.
    [buttons_v1.scad]
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2017-08-23 start the 2.0 PCB design
    [kamaji.kicad_pcb, kamaji.sch]
2017-08-23 minor changes to the 2.0 schematic
    [kamaji.sch]
2017-08-23 reverse the player socket order on v1
    [config_v1.h]
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2017-08-31 try fixing the cutout sizes
    [enclosure_v1.scad]
2017-09-01 change the lcd support height
    [lcd_support_v1.scad]
2017-09-06 fix the top yet again
    [enclosure_v1.scad]
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2017-09-07 Revert "change buttons height"
    This reverts commit 451372d9556a0305292e385cb7759c9dfeb46305.
    [buttons_v1.scad]
2017-09-07 fix the buttons height
    [buttons_v1.scad]
2017-09-08 make the buttons lower
    [buttons_v1.scad]
2017-09-12 Box with a board
    [enclosure_v1_board.scad]
2017-09-12 fix border
    [enclosure_v1_board.scad]
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2017-09-13 Fix top board
    [enclosure_v1_board.scad]
2017-09-13 bolt heads on the top
    [enclosure_v1_board.scad]
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2017-10-02 a few connections on the 2.0 PCB schematic
    [kamaji.sch]
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2017-10-09 pull reset up since it's active-low
    [kamaji.sch]
2017-10-09 add jumper on power, comments
    [kamaji.sch]
2017-10-10 update title on 1.0 schematic
    [kamaji.sch]
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2017-10-12 add a daughter board connector
    [kamaji.sch]
2017-10-17 start the 2.0 schematic from scratch
    [kamaji.kicad_pcb, kamaji.sch]
2017-10-21 psb: add screen, sound, usb, dummy load and ICSP
    [kamaji.sch]
2017-10-21 pcb: add the rest of the components to the schematic
    [kamaji.sch]
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2017-10-22 use 4 parallel resistors for the dummy load
    [kamaji.sch]
2017-10-22 start mapping symbols to footprints
    [kamaji.sch]
2017-11-01 create a board outline
    [kamaji.kicad_pcb]
2017-11-01 move kicad libs to a separate directory
    [kamaji.sch]
2017-11-01 use a graphic display instead of 2004
    [kamaji.sch]
2017-11-18 pcb: delete the sound circuit
    [kamaji.sch]
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2017-12-13 add boost converter, move LCD to a separate sheet
    [boost_converter.sch, display.sch, kamaji.sch]
2017-12-13 use a 6-pin ICSP connector
    [boost_converter.sch, display.sch, dummy_load.sch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]
2017-12-13 add the sound circuit
    [boost_converter.sch, display.sch, dummy_load.sch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]
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2017-12-17 buzzer footprint
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2017-12-17 Fixes for brain and reset
    [main.cpp]
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2017-12-20 add the missing inductor footprint
    [boost_converter.sch]
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2017-12-21 first attempt at laying out the 2.0 pcb
    [boost_converter.sch, kamaji.kicad_pcb, kamaji.sch]
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2017-12-21 flip the signal LED
    [kamaji.kicad_pcb]
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2017-12-22 flip the LCD and re-route the board
    [kamaji.kicad_pcb]
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2017-12-23 fix a couple of silkscreen labels
    [kamaji.kicad_pcb]
2017-12-23 simplify the reset code a bit
    [main.cpp]
2017-12-23 set resetStarted to false
    [main.cpp]
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2017-12-25 fix a resistor value
    [boost_converter.sch]
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2017-12-25 add a missing resistor
    [kamaji.kicad_pcb, kamaji.sch]
2017-12-26 fix track clearance
    [kamaji.kicad_pcb]
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2017-12-28 get rid of the holes on the TO-220 footprints
    [kamaji.kicad_pcb, kamaji.sch]
2017-12-28 replace the button footprints
    [kamaji.kicad_pcb, kamaji.sch]
2017-12-28 fix the buzzer footprint, move usb sockets
    [kamaji.kicad_pcb, kamaji.sch]
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2017-12-30 put together a minimal schematic for kamaji xl to get an idea about its size
    [KamajiXL.kicad_pcb, KamajiXL.sch]
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2018-01-04 Revert "try using software emulated SPI for the LCD"
    This reverts commit f480e49c37e6329675e11cf027eb54b90cdfbea2.
2018-01-05 reverse the control buttons
    [config_v2.h]
2018-01-06 reverse the player socket order
    [config_v2.h]
2018-01-06 fix the test firmware
    [main.cpp]
2018-01-09 3d: fix OpenSCAD compilation errors
    [enclosure_v1.scad, lcd_support_v1.scad]
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2018-03-12 Minor fixes
    [enclosure_v2_board.scad]
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2018-04-11 finish the v3 schematic and map most of the footprints
    [kamaji.sch]
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2019-02-03 v3: draw missing footprints, start layout
    [v3.kicad_pcb, v3.sch]
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2019-04-28 Fix v2 board variant.
    The variant we previously used was removed from arduinoavr package.
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2019-09-08 add a capacitor to fix sound
    [v3.kicad_pcb, v3.sch]
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2022-10-09 Fix CI
    [kamaji_button_v1.STEP, kamaji_button_v1.kicad_pcb, kamaji_button_v1.kicad_sch]
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2022-12-27 button pcb: replace the switch footprint
    [kamaji_button_v1.kicad_pcb, kamaji_button_v1.kicad_sch]
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2023-05-06 Add shell STLs and CAD files for Classic and button
    [bottom_wo_programmator.scad, button_v1_bottom.stl, button_v1_shell.step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]
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2025-12-30 Update KiCAD projects, add Classic V1 schematic PDF
    [kamaji_classic_v1.kicad_pcb, kamaji_classic_v1.kicad_sch]
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

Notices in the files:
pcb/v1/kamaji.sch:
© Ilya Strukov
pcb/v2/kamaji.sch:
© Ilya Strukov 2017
